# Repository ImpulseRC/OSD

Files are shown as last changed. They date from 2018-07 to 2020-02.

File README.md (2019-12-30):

<p align="center">
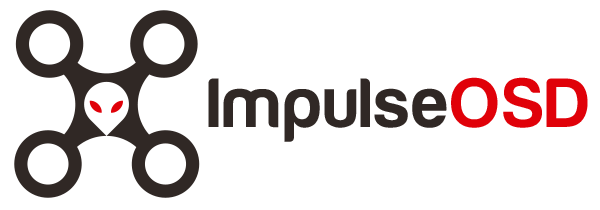
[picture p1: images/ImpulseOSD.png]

</p>

<p align="center">Official documentation resource for the ImpulseOSD hardware and firmware platform.</p>

## Contents

**[Home](https://github.com/ImpulseRC/OSD/wiki)** <br />
**[Getting Started](https://github.com/ImpulseRC/OSD/wiki/Getting-Started)** <br />
**[Betaflight+WolfPDB: Please read!!!](https://github.com/ImpulseRC/OSD/wiki/Betaflight-WolfPDB:-Please-read!!!)**  <br />
**[Rescue flash](https://github.com/ImpulseRC/OSD/wiki/Rescue-flash)** <br />

# Hardware <br />

* **[Wolf PDB](https://github.com/ImpulseRC/OSD/wiki/Hardware:-Reverb-Wolf-PDB)** <br />
* **[Apex OSD](https://github.com/ImpulseRC/OSD/wiki/Hardware:-Apex-OSD)** <br />

# Firmware <br />

* **[General Navigation](https://github.com/ImpulseRC/OSD/wiki/Firmware:-General-Settings)** <br />
* **[Basic Setup](https://github.com/ImpulseRC/OSD/wiki/Firmware:-Basic-setup)** <br />
* **[OSD labels/items](https://github.com/ImpulseRC/OSD/wiki/Firmware:-OSD-labels-and-items)** <br />
* **[Video Transmitter](https://github.com/ImpulseRC/OSD/wiki/Firmware:-Video-Transmitter)**
* **[Battery](https://github.com/ImpulseRC/OSD/wiki/Firmware:-Battery)**
* **[RSSI](https://github.com/ImpulseRC/OSD/wiki/Firmware:-RSSI)**
* **[Camera control](https://github.com/ImpulseRC/OSD/wiki/Firmware:-Camera-control)**
* **[GPS + Magnetometer](https://github.com/ImpulseRC/OSD/wiki/Firmware:-GPS)**
* **[LED strip](https://github.com/ImpulseRC/OSD/wiki/Firmware:-LED-strip)**
* **[Advanced display](https://github.com/ImpulseRC/OSD/wiki/Firmware:-Advanced-display)**
* **[Graphical OSD options](https://github.com/ImpulseRC/OSD/wiki/Firmware:-Graphical-OSD-options)**

# Config Tool GUI

* **[Install](https://github.com/ImpulseRC/OSD/wiki/Config-Tool:-Install)**
* **[Screen Designer](https://github.com/ImpulseRC/OSD/wiki/Config-Tool:-Screen-Designer)**
* **[Fonts](https://github.com/ImpulseRC/OSD/wiki/Config-Tool:-Fonts)**
* **[OSD Settings](https://github.com/ImpulseRC/OSD/wiki/Config-Tool:-OSD-Settings)**
* **[Flashing](https://github.com/ImpulseRC/OSD/wiki/Config-Tool:-Flashing)**
* **[Activation](https://github.com/ImpulseRC/OSD/wiki/Config-Tool:-Activation)**

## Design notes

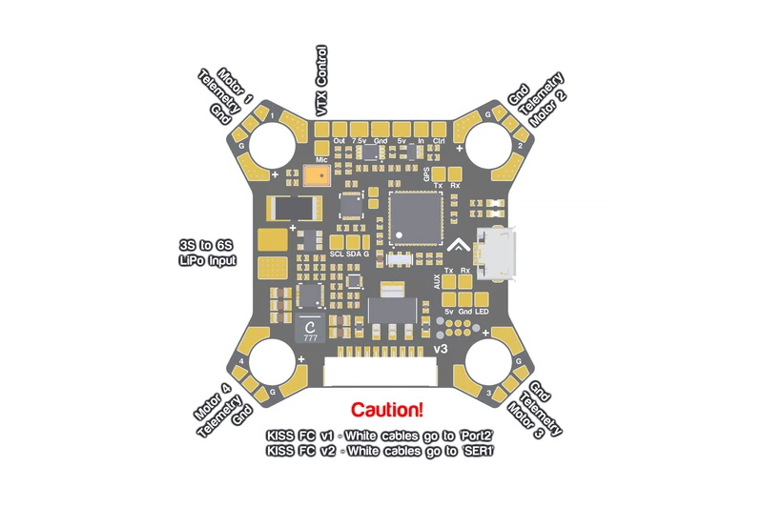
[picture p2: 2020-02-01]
images/Wolf/WolfV3_KISS_Pinout.jpg

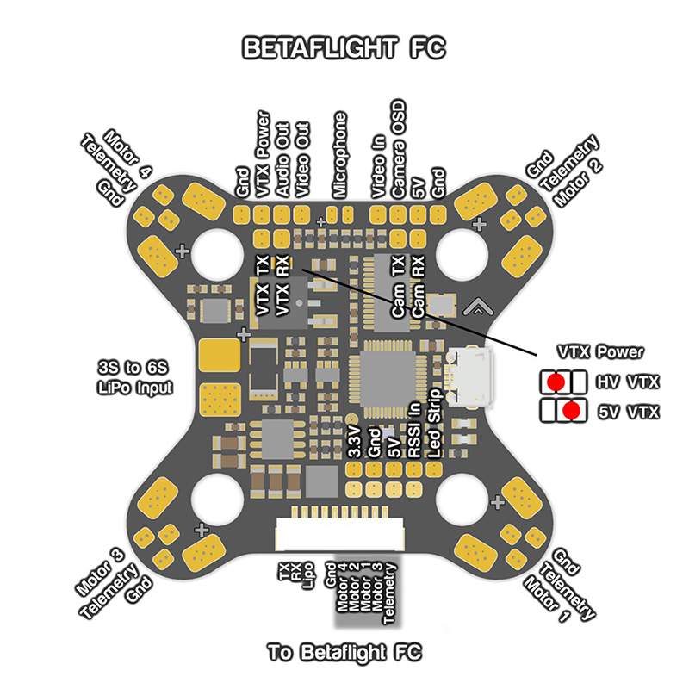
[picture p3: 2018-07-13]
images/Wolf/Wolf_BF_Pinout.jpg

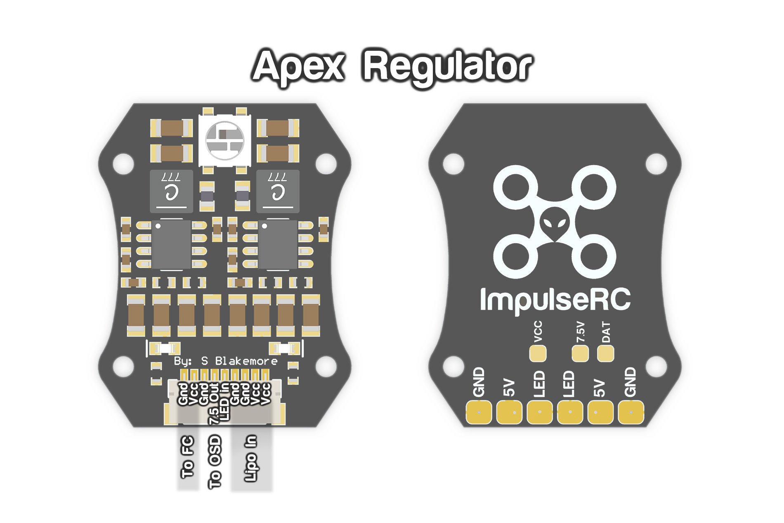
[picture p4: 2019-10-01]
images/Apex_OSD/Regulator_board_pinout.jpg

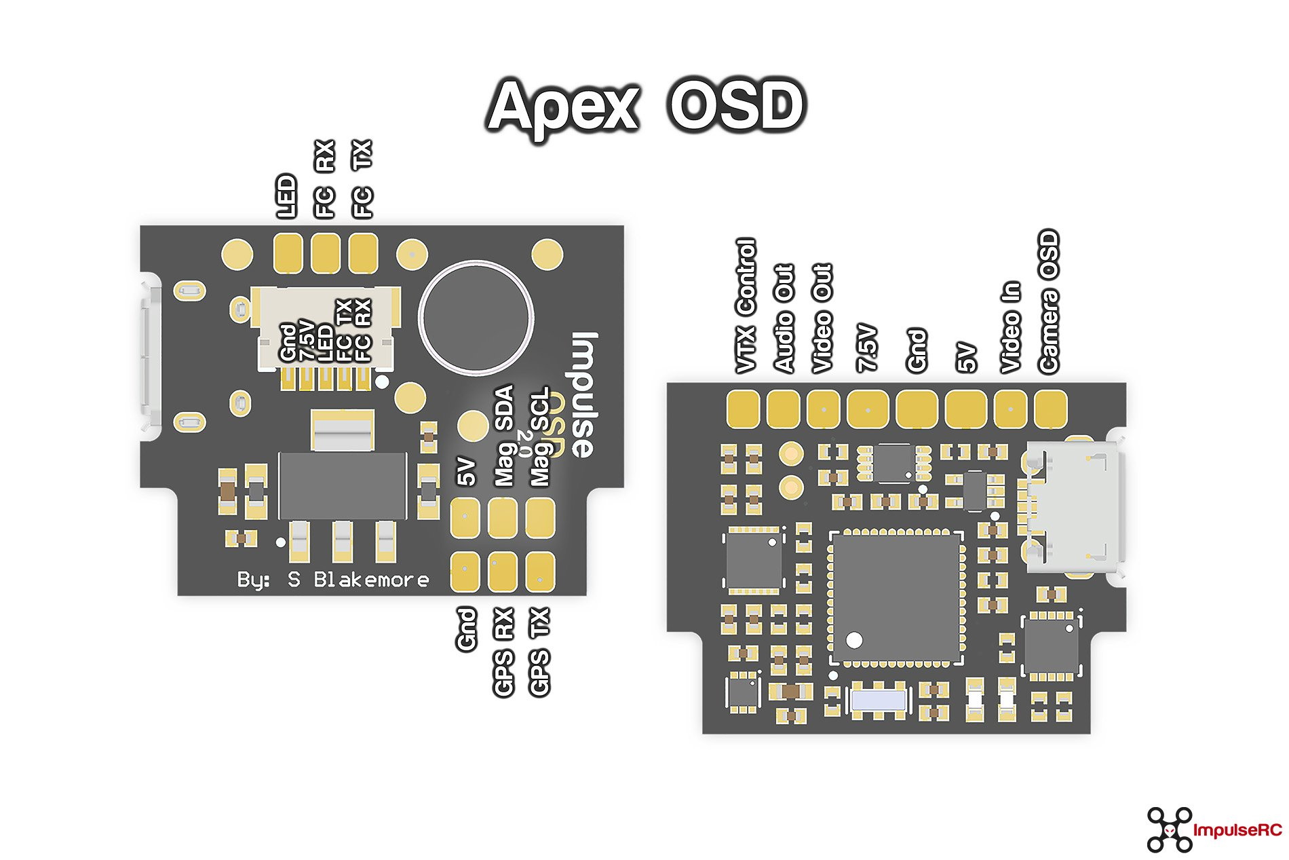
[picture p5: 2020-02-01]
images/Apex_OSD/Apex_OSD_pinout.jpg

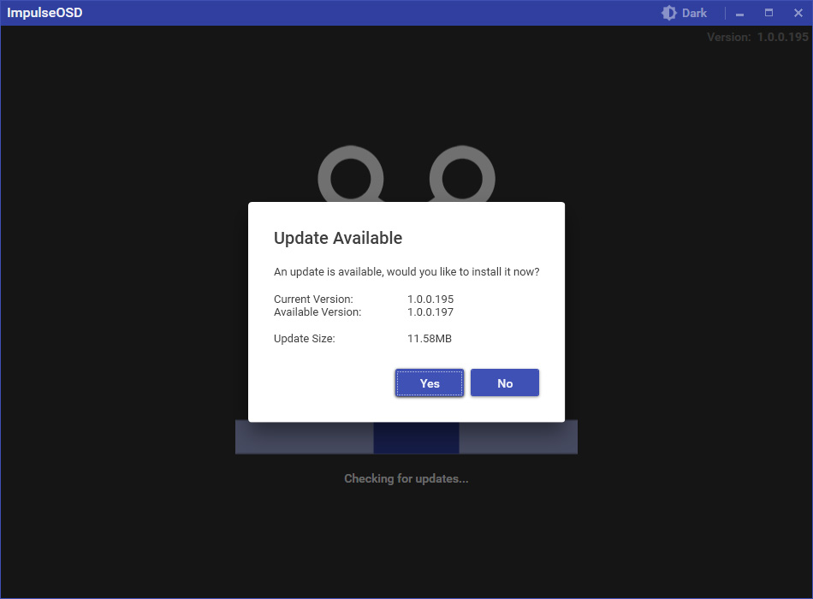
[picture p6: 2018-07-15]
images/ConfigTool/UpdateAvailable.jpg

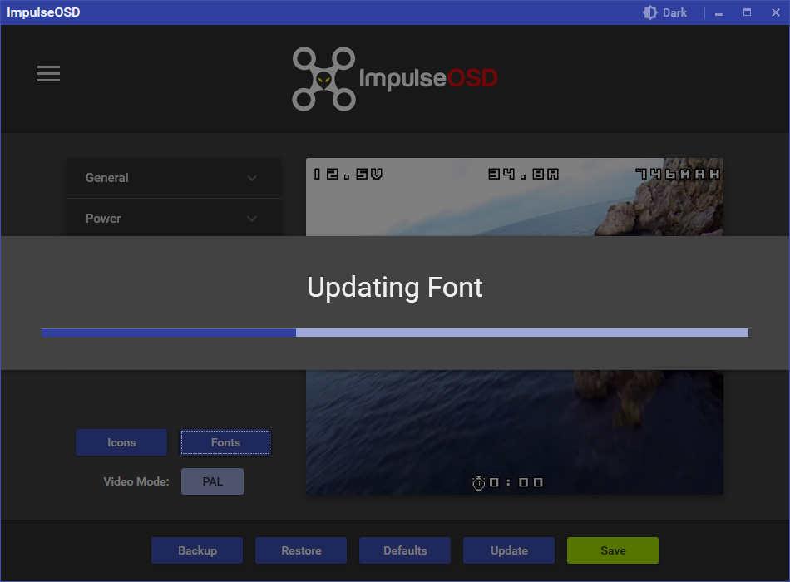
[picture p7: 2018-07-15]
images/ConfigTool/FontUpdating.jpg

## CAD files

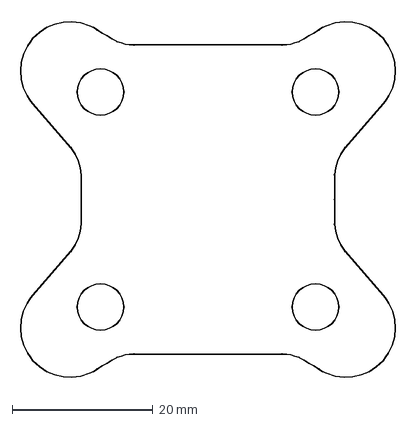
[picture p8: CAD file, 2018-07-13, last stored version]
images/Wolf/Wolf_Outline.dxf
54.3 x 52.0 mm

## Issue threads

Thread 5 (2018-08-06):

Unify pro - Smartaudio + microphone audio

FPVlog, 2018-08-06:
Hi

I read the manual and couldn’t find anywhere if it is possible to wire the Unify so it uses both smartaudio and audio from the microphone.

Is it possible at all? Should I jump the two pads and see if it works?

Cheers

awolf78, 2018-08-06:
Yes, jump the two pads. Solder the SmartAudio wire to the VTX TX pad on the WolfPDB. Then solder a small wire from VTX TX to the Audio pad.

In rare cases this can disrupt SmartAudio communication - then you might have to make a choice between Audio and SmartAudo. Not much we can do about it, that is a design issue of the Unify VTX. TBS recently came out with a Unify version with separate Audio and SmartAudio wire...

mortenb1337, 2019-01-03:
I had the same question, and came here. Did it work for you?

greezmen, 2019-03-28:
any plans for smart audio 2.1 support? or iam doing something wrong  its nit working with my hv pro race v2 unify thank you

awolf78, 2019-03-29:
SA V2.1 already implemented but not released yet, I can get you a beta if you like.

question2019, 2019-04-12:
hi, pls can u send me the link to the beta with SmartAudio 2.1 Support?
Thanks!

redoakleaves, 2019-04-12:
It is supported by the new firmware-version which is out since a couple of days, i guess. You should be able to update it right now.

question2019, 2019-04-12:
works perfect !!! thanks

TinoFpv, 2020-01-04:
Hi guys, noob here needs help.
I got a foxeer predator v4 on a tbs unify pro v3, the impulse ods have from left to right VTX control, audio out, so I have to bridge them?But when I do so i can't here the audio.
What to do?
Thanks and sorry for the noob question, first build.

awolf78, 2020-01-04:
I assume you are using the Apex OSD. Easiest is to strip the SmartAudio wire from the Unify a bit longer and solder it across both the VTX control and Audio pad. Please check that you have the volume turned up on your goggles. Are you sure the audio on your goggles is working?

TinoFpv, 2020-01-04:
Thanks awolf78, it was the jack not going right in.
I soldered now vtx and audio together on the apex osd.It works well.
Last question is what to do with the violet cable coming out from the foxeer.
Don’t now where to solder it :/
Many thanks for help.

awolf78, 2020-01-04:
The Violett (=Purple in Englisch) is the current sensor I guess. That one is not necessary. Make sure the VTX ground and camera ground are both soldered to the common ground pad.

TinoFpv, 2020-01-04:
Purple, exactly!All ground cables are fine.Apex osd is showing the right leds, so I think It is ok.
Thanks again awolf!

MrMPod, 2020-03-01:
> Apex OSD. Easiest is to strip the SmartAudio wire from the Unify a bit longer and solder it across both the VTX control and Audio pad.

but am I right that to change my vtx chanels I need PC computer and ImpulseRC OSD application ?
or is there way to change my vtx chanels and power without computer ?

awolf78, 2020-03-01:
No, you can change those in the field on the OSD menu. Read [here](https://github.com/ImpulseRC/OSD/wiki/Firmware:-Video-Transmitter)

MrMPod, 2020-03-01:
so is it necessary strip  the SmartAudio wire or just solder bridged the two pads VTX Control to the Audio Out pad on APEX OSD (I have already connected audio to my Unify VTX)

awolf78, 2020-03-01:
You can strip the wire longer or bridge the two pads - whatever is easier.

MrMPod, 2020-03-04:
you are right - strip the SmartAudio wire is easier than bridged the two pads :)
and it is working great, thank you very much for help

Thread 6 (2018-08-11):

Wrong ESC Speed/Temp with BLHeli_32?

milindur, 2018-08-11:
Hello,

today I installed the Wolf PDB in my Reverb together with the Bardwell F4 AIO FC (Betaflight v3.4.1). The ESCs are Airbot Wraith32 v2 with latest BLHeli_32 v32.52 firmware (beta). The ESC current seems to be okay, but temperature and RPM are way off.

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

This sounds similar to this issue: bitdump/BLHeli#318

awolf78, 2018-08-11:
Yes, this is a known issue. I have done lots of improvements for BF support lately and I'm overdue for a new release. Need to do some more testing which is challenging with all this rain we have here...

milindur, 2018-08-11:
Thanks! Good to know about the fix, so it is not an issue of my build. If I can help testing anything regarding BF, please let me know.

awolf78, 2018-08-12:
Fixed in V19.8

Closed 2018-08-12.

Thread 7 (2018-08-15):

Wrong KV and Min Voltage in Statistics

milindur, 2018-08-15:
Hello,

I am using the latest firmware for the OSD (19.8) with BF 3.5.0 and Wraith32 BLHeli_32 ESC (with firmware 32.52). In the statistics after a flight the calculated KV and also the min voltage (hopefully) seems to be sometimes wrong:

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

In this case only stats of ESC 3 and 4 are wrong, ESC 1 and 2 seem to be fine. After another flight all ESC stats were affected.

awolf78, 2018-08-15:
Please update to 19.8 by connecting the GUI

awolf78, 2018-08-15:
Is the autonomous telemetry option disabled on all your ESCs?

awolf78, 2018-08-16:
Ok, Wraith V2 ESCs? Not the mini ones, correct?
I have the same on my 6S quad and will beat a few more packs through it. Might have to get used to this since the KV is calculated by voltage and RPM. Somehow the voltage reported by the ESC must have gone as low as 0.3V for some reason which caused such crazy high KV numbers (or negative ones because it overflowed).

milindur, 2018-08-16:
Correct, Wraith32 V2 35A. Since I am still quite new to FPV and mini quads, I primarily did cruising with low to mid throttle and only sometimes pushed throttle to max for testing. I just checked my screenshots. In all cases where the KV was too high or overflowed, the min voltage of that ESC was 0.30V. So maybe this is more an issue of the BLHeli_32 firmware?

Closed 2019-12-30.

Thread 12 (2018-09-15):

No Audio just weird clicking Sounds

Richygoat, 2018-09-15:
Hello,
today i replaced the Steele PDB against the Wolf PDB an i don't have audio anymore.
vTX is the ImmersionRC Tramp.

When i disconnect the Audio wire from the PDB there is silence in the headphone. Connect it back only loads clicking sounds.

Newest firmware ist flashed.

Everything else is working fine.

regards

awolf78, 2018-09-15:
Did you solder the microphone on the WolfPDB? Can you show some pictures how you have soldered everything?

Richygoat, 2018-09-15:
Yes microphone is soldered on. And here are some pictures.

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

Richygoat, 2018-09-15:
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

awolf78, 2018-09-15:
Most probably a defective microphone. Please contact your dealer for a replacement. Sorry this happened to you.

Richygoat, 2018-09-15:
That was my thought too. But when i desolder the microphone this noise sound is still there.

Richygoat, 2018-09-15:
i could try to solder the microphone from my Steele PDB in the Wolf PDB when they're the same.

Richygoat, 2018-09-16:
I have tried the working microphone from the Steele PDB on the Wolf PDB. Still don’t working. After putting it back on the Steele PDB Everything working fine again.

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

awolf78, 2018-09-16:
Sorry this happened to you. Please contact your dealer for a replacement.

Richygoat, 2018-09-17:
Yes. I tried 2 TrampHV. Both are working fine on the Steele PDB.

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

awolf78, 2018-09-17:
OK, then you need to have your board replaced unfortunately.

Closed 2019-12-30.

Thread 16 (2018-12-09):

Some Display Options Not showing When Selected

awmondy, 2018-12-09:
I've searched this thread, impulserc github and googled and could not find an answer to my problem. A few options I selected to show on the display isn't on the screen. For instance, I had the vtx channel and vtx power on the screen. I removed the vtx channel and it was no longer displayed. I added the channel back and it did not show on the screen. Other display options are not showing either. I used the Impulserc app to default the pdb and had the same issue. Has anyone else had this issue?

Impulserc/Wolf fw 22.9
Kiss v1 fw 1.3-rc36c

awolf78, 2018-12-09:
Did you click Save in the ImpulseOSD GUI after you added the VTX channel back?

awmondy, 2018-12-10:
I did click save in the GUI.

FYI - RSSI, timer and GPS data doesn't show at all. I can add and remove
callsign.

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

awmondy, 2018-12-11:
I found what was causing the issue. I added a GPS (BN180). I connected tx to tx and rx to rx, when I should've had tx to rx and rx to tx. I reversed the connections at the pdb and the missing options were displayed on the screen. I find it odd that having the GPS connections reversed could cause some options not to be displayed.

awolf78, 2018-12-11:
It doesn't make sense for the OSD to display labels when there is no data available for them. Some pilots just plug in a GPS occasionally and then they will only see the GPS related labels when it is connected.

Closed 2019-12-30.

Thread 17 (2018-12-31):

Micro Swift 3 Serial Communication Wolf PDB and Kiss v2

Ayougo, 2018-12-31:
Wolf PDB with latest firmeware
Kiss v2 with RC36I firmware
Micro Swift 3 connect via TX/RX  (TX from Swift to RX on Wolf PDB, RX from Swift to TX on Wolf PDB)

Issue: No Internal OSD menu on new swift 3 micro with serial camera control

Yaw left, toward bottom or zero throttle, hold for several seconds, enter menu, select "camera control", Yaw Left  == No Internal OSD menu

mkct93, 2018-12-31:
Same here friend. 😐

awolf78, 2018-12-31:
Go to SETUP->CAMERA CONTROL and change CAMERA CONTROL to SERIAL.

awolf78, 2018-12-31:
Cam RX connected to PDB Camera TX?

mkct93, 2018-12-31:
Yes. I swapped it around both ways in case the camera wasn’t labeled correctly. Still nothing. I’ll try another camera tonight that I know works with the serial connection and post the results. Also I am using the rev1 pdb.

mkct93, 2018-12-31:
Fantastic! I’ll give it a go tonight. Pdb is awesome by the way. Great piece of kit. 👍🏻

mkct93, 2019-01-01:
That was it. Thank you so much.

Closed 2018-12-31.

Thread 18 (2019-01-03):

OSD stopped working

Anckero, 2019-01-03:
My OSD is not showing up anymore with my WolfPDB. I don't get values nor ImpulseRC boot logo.
The green LED is on but the red one is not flashing as it should.
The PDB is not connecting to my PC.

I searched online and found on RCgroups a guy who stopped a firmware update by mistake and he had the exact same issues. So even if my problem is not coming form a bad firmware update I followed the steps.
I temporarily bridged SDA and GND then connected the USB. This trick worked, the red light was flashing and the PDB was recognized by my PC. As an update was available I flashed it and it went well.

But then I unplugged the XT60 and USB and this issue is still there on my next attempt to connect the XT60, no red LED flashing.

I'm using a KISS FC v1.03 FW1.3-RC36i

awolf78, 2019-01-04:
Do the SDA and GND trick again, but this time select Full Chip Erase in the GUI before you flash.

Anckero, 2019-01-04:
Fantastic! All is back to normal.
Thank you very much awolf78! 😃

Oberlurch3000, 2019-05-01:
Please could you tell me how this trick works? I've the same problem since today. Just no OSD in the FPV screen and the red LED is off. WIndows tells me that the device has not been recognized. Why is this happening? I did no changes to it in the last few weeks.

Anckero, 2019-05-01:
Hi @Oberlurch3000
Here is the RCGroups thread I first found the instructions: https://www.rcgroups.com/forums/showthread.php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

Just follow the instructions as per Awolf78's comment on RCGroups and you should be fine. If the problem persists you may have to do the "Full Chip Erase" thing in the GUI as Awolf78 told me to do on this GitHub thread. :)

Oberlurch3000, 2019-05-01:
Wow thanks! I like things that work ;). But very strange that it happend anyway.

Anckero, 2019-05-01:
Yeah it's pretty strange. Mine stopped working like yours, without any reason. But it has been working great since this fix so you should be fine too. :)

Brightontillifly, 2021-07-10:
> Do the SDA and GND trick again, but this time select Full Chip Erase in the GUI before you flash.

this totally worked for me nice one Wolf!

Ub6ib9, 2021-08-28:
Awesome so there is hope. Out of nowhere the osd quit working and gps wasn't getting a lock. I'm hoping this process will work. I'll chime back in after trying.

Closed 2019-01-04.

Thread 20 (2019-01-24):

"Battery Charged ?" show on deplay

climbhi2, 2019-01-24:
Hello,
I would like to thank you for everything you’ve done to make this OSD the best.

I'm running the latest frame ware and have been seeing "Battery Charged ?" come up blanking when I plug in a battery. When I arm the message goes off. Is this new? I have tried to isolate it by changing batteries on my goggles and transmitter. Is this just a message “battery charged?” to remind you to check the battery before you fly or have I changed a setting that I’m not aware of.
Thank You
Tommy

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

awolf78, 2019-01-26:
This is voltage based and appears when you plug in a battery that does not appear to be at charged voltage.

whig0, 2019-07-20:
This warning is shown even with 4.15 Volts. Is it possible to disable it? Or can it be adjusted somehow?
Thanks.

awolf78, 2019-07-29:
I have made it less sensitive and dropped the warning voltage to less than 4.10V per cell. Will be included in next release.

whig0, 2020-09-12:
Unfortunately I still have the problem. The warning shows for me as soon as the voltage drops under 4.1V Per Cell.
Is there still no possibility to just disable it?

awolf78, 2020-09-12:
The warning disappears as soon as your arm. It is just a reminder that your battery may not be fully charged - which is the case at 4.1V.
Alternatively you can add a voltage offset and raise the voltage by e.g. 0.1V in the [Battery menu](https://github.com/ImpulseRC/OSD/wiki/Firmware:-Battery#battery-menu)

whig0, 2020-09-12:
Yes I did that already. But the warning appears as well just with .1V offset at 4.0V :-)
It even shows when not armed.

awolf78, 2020-09-12:
But it disappears when you arm? It is just a reminder that your battery is not fully charged...

whig0, 2020-09-15:
Sorry for late reply.
No it does not disappear. And it's in the middle of the screen.
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

awolf78, 2020-09-15:
Hm, that is very odd. Can you please describe your setup and how you have it wired up? Do you see a message ARMED or DISARMED when your arm/disarm? What version ImpulseOSD is on there?

whig0, 2020-09-16:
It's wired like in the Philipp Seidel Wiringplan.

Impulse OSD Version is V86.25
Kiss FC v2 (1.3RC45y)
4x Kiss ESC 32A
TBS UNIFY Pro32 VTX @7.5V
Foxeer Falkor Cam @5V
No Mic, No GPS, No LEDs
Spektrum Receiver
4S LiPos

Yes, I get the Armed and Disarmed messages.

awolf78, 2020-09-16:
Can you try flashing again?
If that doesn't help I would need a backup of your ImpulseOSD and KISS FC configuration...

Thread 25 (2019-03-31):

No Connection to FC

dawiddi, 2019-03-31:
Hello there,
I just build my first wolf pdb setup with a brand new board and a Kiss FC V1. After updating all firmwares (Kiss on 1.3RC36 Stable and the latest OSD firmware) and do all settings (Dummy VTX, No Logger/OSD) I have the following issue.
After booting up every time the message "Detecting FC Type" shows up. Sometimes after a while, the message just disappears, other times it follows "No connection to FC" and the OSD hides. I already checked the port cable, it seems to be everything ok. I resoldered the cables to the VTX and the cam aswell. The Kiss and the PDB are brand new.

I've read all the issues related to my problem, but could not find a solution. Can you help me?

Thanks a lot.

Hydromaster1, 2019-04-03:
I am having the same issue. Kiss FC V2, tramp vtx, & crossfire. The problem goes away when GPS is disconnected. Using an RDQ  M8N GPS. GPS data appears and disappears.
Thanks for all the hard work and awesome firmware!!!

awolf78, 2019-04-04:
I just released a fix for this issue, please connect GUI and update

Hydromaster1, 2019-04-05:
Update complete and the issue is gone. Only thing I noticed was the home arrow spins continuously.
Could this be due to close proximity to the home point. I only did one test flight about 300 meters out.
Hope to get another flight in tomorrow. Many Thanks!!

awolf78, 2019-04-05:
If the home arrow keeps spinning then the GPS has not been able to establish a fix yet. You can turn the satellites label on which will show you how many satellites the GPS has found. For a first fix it can take several minutes...

Hydromaster1, 2019-04-05:
Got it.
Many thanks!!

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

dawiddi, 2019-04-05:
Many thanks. I couldn‘t try flying yet, but the message disappeared in standby.

dawiddi, 2019-04-07:
So I got the time to test it today. But unfortunately the voltage, power and mah values were way too high (330 V, 150 A etc.) and after a short while it lost the connection to the FC. What should I do?

awolf78, 2019-04-07:
Can you revert to V24.11 and see if you still have the same issue?

dawiddi, 2019-04-13:
Hello,
I just got the chance to test it today. The wrong voltage values are gone, but instead the "Detecting FC Type" and "No connection to FC" comes back after a few seconds of flight.
Any further suggestions?

awolf78, 2019-04-13:
If you reverted to V24.11 and you get a "Detecting FC Type" then there is definitely something wrong with your board or wiring. Do any of the chips or regulators get very hot shortly after you plug in? Can you post some pictures of your wiring?

dawiddi, 2019-04-14:
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

I already measured the wiring to the Kiss FC, all cables are okay. When I touch the PDB after powering, it stays cool. It seems good. But my Kiss FC gets very hot near the USB port. I thought, that would be normal because it is a new one.

I attached some pictures of my wiring.
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

awolf78, 2019-04-14:
Wiring seems OK. What type battery are you running? 4S, 5S, 6S?
VTX is connected to HV power - not sure which VTX you are using.
Did you change anything in your serial configuration of your KISS FC. Check in the KISS GUI Advanced tab. Please post a screenshot of that.

dawiddi, 2019-04-14:
Battery is 4S, I use a Unify Pro HV, that works great.
I attached a screenshot of the advanced tab.
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

awolf78, 2019-04-14:
Strange that your Yaw Filter is at 92 - should be at 35 or 40. But that should not matter for the FC communication. Do you have another FC you can try?

antantantantant, 2019-05-03:
Hi!
I have this same 'detecting fc type' - 'no connection to fc' problem with wolf pdb + matek f405-std combo. PDB seems to work fine, it has updated itself to v40 something, fc is working and is configurable in betaflight app, it's connected to a crsf receiver and reacts to controls, I can arm (and probably fly) the quad, but can't control the PDB with stick commands or get BF OSD items to show on screen etc.
I've attached some images of my wiring (sorry for the mess :) ). I'll make more photos if you need to see details, just point me where you need to look.
Any suggestions appreciated :)
Thanks!

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

awolf78, 2019-05-04:
Did you read [https://github.com/ImpulseRC/OSD/wiki/Betaflight-WolfPDB:-Please-read!!!](url)?
Configured MSP for the UART you are using for FC communication to the PDB?

antantantantant, 2019-05-04:
Believe it or not, I missed the article, although I searched for instructions :/ Sorry!
Anyway, just set up BF as instructed and everything works now :)
Thanks!

AiroFpv, 2019-05-11:
So i have also been having this same issue, new board, connect to gui and flash newest fw. When i first plug in, osd is fine and i can access menus for a bit then "no connection to fc" shows up. Same if i go for a fly, after a few seconds, osd goes away and no connection to fc. Any tips?

AiroFpv, 2019-05-11:
Link on your last reply doesnt work either. Cant read the please read!

awolf78, 2019-05-11:
[Please read](https://github.com/ImpulseRC/OSD/wiki/Betaflight-WolfPDB:-Please-read!!!)

awolf78, 2019-05-11:
Can you describe the setup you are running? FC type, lipo voltage, etc.

AiroFpv, 2019-05-11:
Sorry, i deleted the link comment cause i am running kiss v1 fc and 32a escs, 5v unify, 4s with caps on esc's in preparation for 6s transition.

awolf78, 2019-05-11:
What FW are you running on the KISS FC?
Not sure if you have tried to run 6S on your rig, but the KISS V1 cannot handle 6S lipo voltage. Most of the time the voltage regulator gets damaged if you try to run 6S and although it still flies you get these connection issue. Not 100% sure that is the issue, just one possibility.

StevenFpv, 2019-09-24:
ciao ragazzi, ho lo stesso problema appena collego la lipo mi rimane il logo impulse con la scritta DETECTING FC TYPE.  una build che funzionava, ho sostituito con una nuova kissv2 e nuova ricevente r9 slim plus, ho aggiornato con l 'ultimo fw di impulse e l ultimo su gui, aggiungendo il GPS. ho staccato il gps e provato fw precedenti ma non sono riuscito a risolvere il problema.

vladsubbotin44, 2019-10-29:
pdb wolf writes in OSD Detecting FC Type. flight controller mamba f405 mk2. whats problem ?

sblakemore, 2019-10-30:
@vladsubbotin44 please ensure that you have updated to the latest version of ImpulseOSD. Can you also check that you have MSP enabled for the correct serial port in BF and that you have soldered RX to TX and TX to RX.

AiroFpv, 2019-11-09:
So, something really weird just happened, went to update the osd, run
impulseosd plug in, says do you want to update, click yes then error
message saying lost connection try power cycling and re run gui. Now when i
plug in the computer it says that device isnt working correctly, impulseosd
gui just sits there and doesn't see it and impulserc driver fixer doesnt
see it either. No flashing heartbeat, should i try to solder sda and gnd or
did it fry?

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

awolf78, 2019-11-09:
[https://github.com/ImpulseRC/OSD/wiki/Rescue-flash](url)

blackdrone911, 2020-01-12:
> If you reverted to V24.11 and you get a "Detecting FC Type" then there is definitely something wrong with your board or wiring. Do any of the chips or regulators get very hot shortly after you plug in? Can you post some pictures of your wiring?
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
shneakypete, 2020-07-05:
Had this issue… for me the harness on the pdb had come loose from the solder joints and was getting intermittent connection. Ended up replacing the pdb cause when I tried to resolder the traces came off

darkjedi15486, 2020-07-05:
I'm not using a pdb. Im using the kiss 4 in 1 and the kiss v2  with apex irc osd and regulator board

awolf78, 2020-07-05:
First I would re-seat the connectors and make sure the pins inside the connectors are not bent in a weird way. I would still route the cables above the FC to eliminate any possible EMI issues (not every ESC is the same even if it is the same brand). If all of that doesn't help you can try a new Apex OSD harness.

darkjedi15486, 2020-07-05:
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

Well thats how I have mine wired up. I moved the wires away from the motor solder joints and reflashed the osd board and had a 4 min flight with no issue so hopefully its a problem thats gone for good.

LocNgu, 2020-07-10:
I am having the same "no connection to Fc" Problem.
I am running Fettec Fc, Fettec 4in1, Apex Regulator, Apex Osd Board, all wired up using the Kiss Harness, 6s, low esr cap, and fettec spike absorber. I tried running the wire over the fc and powering the Fc from the regulator board instead of the esc. Reflashed everything to most recent updates as of today.
I can reproduce the issue pretty consistently. Every time the amp draw goes over aprox 5A the issue occurs and go away when amps falls back.

awolf78, 2020-07-10:
1. Remove the GND wire from the ApexOSD harness between Apex Regulator and Fettec FC
2. Remove the extra Lipo wire between Fettec ESC and FC
3. Add a GND wire between ApexOSD (can use e.g. GPS GND) and Fettec FC (use any GND that is convenient)

LocNgu, 2020-07-13:
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

Did all the steps above and they do help. Issue doesn't appear that often, but still does from time to time. Still not quite what one would expect from a pretty expensive osd board.

awolf78, 2020-07-13:
There are also some firmware fixes, not only on our side, also on KISS. What KISS FW are you using?

darkjedi15486, 2020-07-13:
I'm using rc40i on my v2.

awolf78, 2020-07-13:
Consider upgrading to 40o. Alexander Fedorov has also made some changes (we worked closely together on the communication issues). You can find his latest FW on Patreon.

darkjedi15486, 2020-07-13:
Is 40o available on the kiss gui

awolf78, 2020-07-13:
Yes

LocNgu, 2020-07-14:
>
>
> There are also some firmware fixes, not only on our side, also on KISS. What KISS FW are you using?

FETTEC_KISSFC-1.3-RC40o

ebeez, 2020-09-12:
Hi,
Can anyone post a picture of how they have used the Apex regualtor/OSD wiring harness to the FC? I am still getting the "connection lost to FC" on my build: Fettec 45 ESC, Fettec FC (both flashed to most current version), apex regulator board/OSD

awolf78, 2020-09-12:
1. Route OSD wires above FC, not between FC and ESC (or below ESC)
2. Remove GND wire between FC and Apex Regulator
3. Remove Lipo+ between FC and ESC
4. Add GND wire between FC and ApexOSD (any GND pad on either side will do).

ebeez, 2020-09-12:
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

Thank you for the quick response! Will give it a shot.

ebeez, 2020-09-14:
Thank you!!! Worked like a charm!

blackdrone911, 2020-11-14:
Hello again,
now I have two v3 PDBs where the red LED is constantly on.
The trick with SDA and Ground doesn’t work.
Some questions:
1. Why this happened the second time?
2. How could it be solved, detected the broken part?
3. Is the problem known from the manufacture?

I am really tiered with this PDB after spending so much time to find the problem :(

awolf78, 2020-11-14:
Did you select "Full chip erase" when you forced the bootloader by bridging SDA and GND?

blackdrone911, 2020-11-14:
I can’t select anything. The software doesn’t detect the PDB. I tried with windows and also with MacOS.
Than I removed all solderings (cam, ESCs, FC and so on) and tried again. Same result.

awolf78, 2020-11-14:
When you bridge SDA and GND and plug a Lipo in - does the red LED start blinking then?

blackdrone911, 2020-11-15:
No

awolf78, 2020-11-15:
OK, I suggest you open a support ticket with the dealer you bought the PDBs from - it is up to them to decide how to handle this.

tommymcnab, 2021-07-21:
Having an issue with my gen one mr Steele Alien setup had it saying no connection to fc and then I hooked it up last night al of the sudden started working was micking around with it and the video started becoming grainy when I shook the unit and then it just dropped out back to no connection to fc I updated the fc and have also taken it apart and found two of the esc had loose wires still no fix though have resoldered connections to cam video transmitter am quite baffled with what to do so anything will help thank you in advance!!!!!!!

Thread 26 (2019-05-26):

Foxeer Predator V3 mini OSD + Futaba RSSI

DrHasch, 2019-05-26:
Hello there,

I connected my **Foxeer Predator V3** to the PDB but i am not getting into the menues. Hooked the  OSD pad to the OSD pin of the cam and the ground pin to the pad of the supply. I tried alot of settings but none of them worked.

As i wanted to use my old **Futaba T7C** i got myself a **ElgaeRX E6208 8CH Mini** receiver from Bangood, which is working fine and does his job. As it has a **RSSI** pad i wanted to ask whether I can connect it directly to the RSSI in pad of the PDB?

Thanks alot,
Thomas

awolf78, 2019-05-26:
https://github.com/ImpulseRC/OSD/wiki/Firmware:-Camera-control#troubleshooting

https://github.com/ImpulseRC/OSD/wiki/Firmware:-RSSI

DrHasch, 2019-05-26:
Already looked up this pages but it did not work

awolf78, 2019-05-26:
Did you wire up the OSD wire of the Predator camera? How did you wire it up? Can you post a picture?

RSSI: Yes, try connecting it to the RSSI pad on the WolfPDB. Then you have to see what readings you get and adjust min and max accordingly.

DrHasch, 2019-05-26:
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
Gnd of the camera (black cable) to the gnd pad on the supply of the camera on the PDB. White cable to the OSD pin on the board.

For the RSSI, where can i look up the readings?

awolf78, 2019-05-26:
Try removing the gnd wire coming from the OSD plug on the camera. That is not necessary anyhow since you already have the camera gnd connected.

RSSI: I don't know what RSSI values your receiver will output - that could be different even if you have two of the same. You will have to look at the values in the SETUP->RSSI screen in the OSD while keeping your radio close (about 1m or 3ft distance) or move it far away (or turn it off).

DrHasch, 2019-05-27:
So i managed to get into the camera control. Somehow it dit not work when i had the setting on predator.

The RSSI pin provides a voltage of 3V when connected and 0V when the remote is switched off. But the RSSI IN pin on the PDB does not really read it.

awolf78, 2019-05-27:
Did you set the RSSI channel to "ANALOG" in SETUP->RSSI? On the bottom of the screen you can see the values.

DrHasch, 2019-05-27:
Yes i did. The value just jumps from 0 to maximum 3 not more... But on 3V it should be like 2000? Am i right?

awolf78, 2019-05-27:
Connect GUI and update to V44.12.
Looks like I picked the wrong ADC channel for the RSSI input - sorry about that.

DrHasch, 2019-05-27:
No problem ;) thanks for the help

Closed 2019-05-27.

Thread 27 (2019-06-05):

GPS not detected

Anckero, 2019-06-05:
Hi,

I'm having a hard time making my BN-180 module work with my Wolf PDB.
Here is my setup:
- KISS FC v1.03 FW1.3-RC36i (latest update available)
- Wolf PDB  Rev1 FW45.12 (latest update available)
- GPS BN-180

The GPS is wired correctly to the Wolf PDB, it flashes in blue and after a bit of time it flashes in red too (meaning it got a GPS fix).
Just in case, here is my wiring:
BN-180 red wire (3.0V-5.5V) → "5V" pad of the PDB (on top of the "GPS TX" pad)
BN-180 green wire (RX input) → "GPS TX" pad of the PDB
BN-180 white wire (TX output) → "GPS RX" pad of the PDB
BN-180 black wire (GND) → "Gnd" pad of the PDB (On top of the "Mag SCL" pad)

I turned on all the GPS items in the OSD but there is no data shown when I leave the OSD settings.

Could you tell me what I missed?
I noticed my FC is getting really hot when I plug the LiPo. The mAh count is going crazy fast!
I tried to unplug the GPS, same issue. Then I removed the 4 GPS wires from the PDB and no more overheating!
That's really strange because I checked and there is no shortcut between the GPS wire (without the GPS module connected to them).

A friend with a Kiss FC v2 and Wold PDB is facing the exact same issue with a BN-220 which is exactly the same hardware as my BN-180. No data and overheating.
I saw, here on GitHub, that you (the ImpulseRC devs) used a BN-180 in the development process so I really don't get why mine is not recognized.

Thanks in advance

awolf78, 2019-06-07:
Can you post some pictures of your setup please? I also need to know what else is connected to the PDB and how.

Anckero, 2019-06-10:
Hi awolf78,

I brought my setup to my work place and a colleague from the electronic team checked everything. We tried to wire up everything again and it worked.
The only difference was that I twisted the wires in the first place and my colleague told me that the power wires could create problem on the RX and TX wires. Now with strait cables the Wolf PDB and the GPS are talking to each other.
I will close this issue then, sorry for the inconvenience. :)
I didn't know that twisted wires could have this kind of effect.

Thanks for your support!

Closed 2019-06-10.

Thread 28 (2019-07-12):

Steele PDB only sometimes audio

Dragon-FPV, 2019-07-12:
Hello,

unfortunately I have no sound any more (it worked fine). I don't know when it started and how (perhaps crash), but now I only have sound for some time when I hit something (e.g. a branch) during the flight without crashing. But just for a while, than the sound is gone again.
It seems like a loose connection, but where?

I tried everthing, all wires are ok and correct soldered, I replaced them ... but at the end the same issue. I also didn't find out what I can do by myself to simulate what happens due hitting something.

I guess microphone is working as there is sound again and again. And it's fixed on the PDB.

What else can I try / could be the reason?

thx and greetz

(KISS FC V2, KISS ESC 32A, Steele PDB, TBS Unify Pro V3, 6S)

rauar, 2019-12-24:
I think this is the wrong repository. Steele PDB should be here: https://github.com/awolf78/KISS_OSD

Closed 2019-12-30.

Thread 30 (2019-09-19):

Cant connect to my wolf pdb with ImpulseOSD app in windows

charalambos12, 2019-09-19:
After updating to the last version of impulseosd app in windows i cant connect to my wolf anymore and i have the message in the attachment. What can i do?
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

awolf78, 2019-09-20:
Disconnect everything, reboot your PC, try again.

charalambos12, 2019-09-20:
Did it many times. Problem did not solved. Before updating the app everything was working perfectly.

awolf78, 2019-09-20:
Bridge SDA and GND pads temporarily. Plug in Lipo. Remove SDA and GND bridge. Connect USB and GUI and flash again, but this time click on "Full chip erase" before you flash.

charalambos12, 2019-09-20:
Thank you for your support!

charalambos12, 2020-01-27:
hello, after doing the procedure, at the end when i open impulseOSD program, i have a new message saying unexpected error, power cycle the device and I cannot continue with the re flashing. I have the same problem with two wolf pdbs v1 (they are working perfectly, except the connection with gui). Thank you in advance.

awolf78, 2020-01-27:
Do you have a different Windows PC or Laptop you can try?

charalambos12, 2020-01-27:
I tryied with mac laptop and I successfully updated the pdb to the latest version.

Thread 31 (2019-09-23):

Wolf PDB won't connect to Impulse OSD app

briankalski, 2019-09-23:
I can't get the Impulse OSD app to see my Wolf PDB.  I did flash the Steele PDB firmware to the board which I am assuming is the wrong firmware.  Is there somewhere I can get the Wolf PDB firmware?

awolf78, 2019-09-23:
How did you flash the SteelePDB firmware on the WolfPDB?

briankalski, 2019-09-23:
Using Xloader.  It was my first quad.

awolf78, 2019-09-23:
XLoader cannot flash the WolfPDB. Does the WolfPDB work (red LED is blinking and shows OSD)?

briankalski, 2019-09-23:
Everything works fine.  The OSD works.  I just can't connect to ImpulseOSD to change my OSD settings.  I ran the driver fixer and that won't connect either.  I tried a Mobula7 and it worked with that.

briankalski, 2019-09-23:
The last time I changed the OSD settings I had to unplug port 2 and flash the Steele PDB config tool.

awolf78, 2019-09-23:
The ImpulseOSD GUI does not work with the SteelePDB. You will have to flash the config tool if you want to make changes to your OSD.

Closed 2019-09-23.

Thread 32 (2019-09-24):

WOLF REVERB PDB OSD Not Recognizing KISS FC v2, multiple quads on powerup.

Struggen, 2019-09-24:
I have 2 Reverb's, both running KISS FC v2 & Wolf PDB rev 2 on latest firmwares that are experiencing failures to recognize the FC when the battery is connected. Reconnecting the battery temporarily resolves the issue. It is occurring every almost every other battery. The problem started occurring after I updated the PDB and KISS GUI's and then updated the firmware for both.

ReverbAlpha
Reverb 5"
Wolf PDB/OSD Rev 2
KISS FC v2
KISS 25amp ESC's
Frsky X4R-SB
ImmersionRC Tramp HV
RunCam Eagle 2
BN-220 GPS

ReverbBeta
Reverb 5"
Wolf PDB/OSD Rev 2
KISS FC v2
KISS 32amp ESC's
25v caps on ESC's
Frsky X4R-SB
ImmersionRC Tramp HV
Foxeer Predator Mini 3
BN-220 GPS
LED's on the FC powered by 5v Diatone regulator

awolf78, 2019-09-25:
Can you please update to V55.15 I just pushed?

Struggen, 2019-09-25:
I have updated one quad to 55.15 and have not had the issue occur during bench testing.

Closed 2019-10-24.

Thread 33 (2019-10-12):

OSD will not centered

carloscampos775, 2019-10-12:
Can't get APEX OSD to center vertically using 57.15. Can't move items to the top of the screen. Using RunCam Swift Mini 2 with TBS Unify Pro 5v

sblakemore, 2019-10-13:
What display device are you using, goggles or screen of some kind? Different displays often show different portions of the image.

Can you please get some DVR footage so we can see how things look?

Might also be worth doing a flash with full chip erase enabled to make sure the config is clean.

carloscampos775, 2019-10-13:
I'm using Fatshark HDO’s with RapidFire. I'm not having this problem with the Wolf Reverb PDB only the Apex OSD. It's also cutting off the back/exit item in the OSD menus. I will try the full chip erase and update the issue.

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

carloscampos775, 2019-10-13:
This is after a full chip erase. Still not working correctly. I have also tried another camera but the problem still persists.

Default OSD layout after full chip erase:
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

This is what I need to do in the configurator to get the OSD items to show on screen:
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

Herbiefpv, 2019-10-14:
I am also having this exact issue. I can adjust the osd side to side but it will not let me move it up. I can see something barley at the bottom. I also tried re flashing but no luck.

Herbiefpv, 2019-10-14:
Awesome thanks Sean!

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

sblakemore, 2019-10-15:
Thanks again for the feedback, I believe I just fixed this. We should have a new release soon for you to try!

sblakemore, 2019-10-15:
If you would like to test a Beta release with the fix I can enable your OSD for Beta updates. All you need to do is connect the OSD to the GUI and then press Ctrl+Shift+D and you will get a popup with your hardware ID. Then just hit Ctrl+C to copy the ID and paste it in here and I'll set it up for you!

carloscampos775, 2019-10-15:
I would like to try the beta. Here is my hardware ID

Device ID: 0011 1025 4847 750A 2037 7341

awolf78, 2019-10-15:
Please download the beta GUI from here:
[http://osd-storage.impulserc.com/deploy-beta/setup.exe](url)

That should offer you V59.15. Let us know how it goes.

carloscampos775, 2019-10-15:
Looks much better. If you could get it to center just a little high that would be perfect.

Default look after flashing
###
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

Herbiefpv, 2019-10-15:
O was i suppose to use a certain gui? I just used the latest one i got the
other day but it will centered mine lol

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

carloscampos775, 2019-10-15:
I was able to center the OSD by using the Advanced options. However, I have gotten a flickering OSD twice now since updating

Video of issue:
https://www.dropbox.com/s/xo40cu8j2zytp4t/PICT0051.AVI?dl=0

sblakemore, 2019-10-16:
@Herbiefpv Beta GUI not a requirement for this update, you will be fine :)

@carloscampos775 Vertical jumping like that is to do with the sync level your camera is putting out. You should be able to fix it by adjusting the sync detection level using the camera settings dialog in the GUI. There is a slider in there you can move up or down, will take some trial and error to find a value that works for you. Looks like it's about on the edge so probably will only take a small movement up or down to be stable.

carloscampos775, 2019-10-16:
@sblakemore I found the camera sync setting. I think i'm good. Thanks for your help ;)

Closed 2019-12-30.

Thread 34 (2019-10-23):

Apex OSD camera control w/ Foxeer Predator v4

bosbefok, 2019-10-23:
This camera has Day, Night, LED, BW mode presets which you can change by long pressing the right button on the remote control board.  I'm having an issue where camera control automatically changes to the next preset when you enter the camera control menu.

All camera control settings are stock with reference voltage of 2.33v.

Any suggestions?

awolf78, 2019-10-23:
What happens if you are not in the camera control menu? It does not change the Day, Night, LED, BW preset then?
The default reference voltage is 3.3V, not 2.33V

bosbefok, 2019-10-23:
It only changes mode when I enter the camera control menu. Sorry, ref voltage is set to 3.30v.

bosbefok, 2019-10-27:
Is this something you can fix in the next update?

awolf78, 2019-10-27:
Not 100% sure yet, but we think we came up with a possible fix for this.

bosbefok, 2019-10-27:
Great. Let me know if I can assist in any way with testing.

SRWieZ, 2019-10-31:
I have a similar problem. My camera is constantly changing mode all the time whatever I do.
When I enter in a menu it constantly trying to go right. (in both menus, external and internal osd of the camera)

Board : Apex OSD
Camera : Runcam Micro Swift 3
Ref voltage : 3.2

bosbefok, 2019-11-08:
Hi Alexander, any progress with this issue?
I've noticed sometimes the mode is being changed now just when I open the OSD menu, even without accessing camera control menu. Doesn't occur every time but has happened on a number of occasions.

awolf78, 2019-11-08:
Unfortunately this is not going to be an easy fix since the chip does not behave like we were expecting. We have not given up on this yet, but a solution for this may take quite a bit longer.
As a workaround you can get a Runcam Camera Control board and set the camera control in the OSD to "serial". That will work for sure and not have any mode changes.

bosbefok, 2019-11-08:
Will setting the camera control to serial also disable the camera control functionality if it is wired for analogue? I've resorted to just pulling out the OSD wire from the camera for now, but if this is a way to do it in the OSD settings it would be better as I could enable when needed, and the disable once changes are made.

awolf78, 2019-11-08:
No, unfortunately not. The OSD wire from the camera must be connected to the Runcam camera control board for this issue to go away. Otherwise it is better to keep it disconnected.

AiroFpv, 2019-11-21:
Im having the same problem where it switches all the time. Running the johnny edition runcam. Still no fix?

awolf78, 2019-11-21:
Your best chance is using a Runcam camera control board and set the camera control output on the OSD to serial.

awolf78, 2019-11-28:
OK, possible workaround which works on the JohnnyFPV Runcam Swift Mini 2: Set the "Camera Sync" level to 200.
You can set the "Camera Sync" level in the GUI (click on the three stripes on the top left and then on Camera setup) or in the OSD menu (yaw left and hold for more than 3 seconds, SETUP->CAMERA CONFIG->CAMERA SYNC.

dweight, 2019-12-10:
I'm having the same issue with runcam swift micro v3 - your workaround helps but I can't change any settings now. This camera supports uart control is it possible to switch it on with the osd board? How should I wire it then?

awolf78, 2019-12-10:
Leave the wire where it is, but it to serial in the menu: SETUP->CAMERA CONFIG->CAMERA CONTROL and set it to SERIAL. You may have to change to serial mode on your camera as well, please check their documentation.

awolf78, 2019-12-30:
The preset switching issue has been fixed with V65.18 (not released yet when I wrote this). I am locking this conversation for others that may have the same issue. If you still experience issues with camera control, please open a new issue.

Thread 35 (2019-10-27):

Apex OSD no image no OSD

jesbombero, 2019-10-27:
The Apex OSD board I received when connected to camera and vtx, nothing is displayed in goggles. Channel is broadcasting but just grey screen, voltages from regulator are all correct and led lights show it is communicating with KISS V2 FC????

sblakemore, 2019-10-27:
Hi mate, this tracker is for issues to do with the ImpulseOSD firmware itself. For more general support requests or hardware problems can you please contact ImpulseRC support and they should be able to help with troubleshooting!

jesbombero, 2019-10-27:
Ok sure, thanks

Justin Smith

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

Closed 2019-10-27.

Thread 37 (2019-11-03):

Unify can not be configured

warp2, 2019-11-03:
Hi I can't configure my unify pro32 over OSD nor LUA script on the Taranis. Video is working with all other stuff (GPS, Battery...)
I have connected:
- 7-26V In (unify) to HV Power at the Wolf PDB
- GND to GND
- Video (unify) to Video Out at the Wolf PDB
- CRSF RX (unify) to VTX TX at the Wolf PDB
Any suggestion?
Or can I connect the CRSF RX to the Kiss as normally when having a setup without Wolf PDB?
Thanks a lot

awolf78, 2019-11-03:
Connect your Unify Pro32 to the TBS Agent and switch CRSF RX to SmartAudio.

warp2, 2019-11-04:
this did the trick, thanks for the tip

Closed 2019-11-04.

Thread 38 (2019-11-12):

Led Strip Not Changing Color

dsalexander99, 2019-11-12:
I installed the led strips provided with the apex frame and they only blink red. I cannot change the color through the apex osd.

awolf78, 2019-11-13:
Please read [https://github.com/ImpulseRC/OSD/wiki/Firmware:-LED-strip](url)

dsalexander99, 2019-11-13:
I’ve already read the info provided. I go thru the osd menu to led strip and try to change mode and color but nothing happens. It’s just stuck blinking red in the “knight” mode.

awolf78, 2019-11-13:
Can you post a DVR what you are doing?

dsalexander99, 2019-11-23:
https://www.dropbox.com/s/7y3exxyjwp1n5ge/Video%20Nov%2014%2C%208%2012%2021%20AM.mp4?dl=0

dsalexander99, 2019-11-23:
That’s a link to the video. Bare with me, I couldn’t get my dvr to record.

awolf78VDRS, 2019-11-23:
LED #1 is the one on the regulator board. LED #2-#7 are the ones that are in Knight mode. You need to select those and change the function/color for them

awolf78, 2019-11-23:
LED #1 is the one on the regulator board. LED #2-#7 are the ones that are in Knight mode. You need to select those and change the function/color for them

dsalexander99, 2019-11-23:
Thanks, I figured I was doing something wrong just didn’t know what.

Closed 2019-11-23.

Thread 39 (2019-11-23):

Won’t connect to configurator

mReXiTuS, 2019-11-23:
Hi Alex,

I was updating my wolf pdb with latest firmware and battery slipped out during process. Now I can’t connect to Impulse OSD configurator, it’s not recognized.

I tried shorting SDA and GND pins as you suggested in different threads, but it doesn’t work and I still have only green led.

However, I was able to enter DFU mode and DfuseDemo app can recognize DFU device, but I would need firmware file so I can re-flash it. Can you please send me something? Or is there any other way how to make it work? Afaik STM MCUs cannot be bricked and there is always way to reflash it either over DFU or worst case with STLink.

Thanks in advace.

sblakemore, 2019-11-23:
Hi,

Sadly we can't give you a copy of our bootloader to flash over DFU, I genuinely wish we could but we would have our code stolen if we didn't protect it.

If you can't flash it by shorting SDA and GND then you can ship it back to ImpulseRC and we will try to recover it for you. If you want to go that route please just open a support ticket with ImpulseRC.

Cheers

Closed 2019-11-23.

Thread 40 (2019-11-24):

No audio only SmartAudio

dsalexander99, 2019-11-24:
I can’t get any audio from the onboard mic. I have the unify pro 5v with the audio cable jumped across the audio and vtx control pad on the osd. I can control my vtx but I have no sound. Any ideas?

awolf78, 2019-11-24:
Do you have audio on any other quads you have that works?
Are you sure the volume on your goggles is turned up? Does the earpiece work you use?

dsalexander99, 2019-11-24:
Goggles are the FatShark attitude v5 which have the volume on high from the factory. The audio worked when I first built it then I ran into the problem that I couldn’t change vtx settings through my osd. So I jumped the audio and vtx pad and that gave me the ability to control my vtx but lost audio from the mic onboard. And yes I’ve tried different earbuds and they all work on other builds.

dsalexander99, 2019-11-27:
Am I just gonna have to choose between vtx control and audio ?

sblakemore, 2019-11-27:
@dsalexander99 this Issue tracker is really only meant for software bugs with ImpulseOSD. The problem you are having is not something which can be fixed in software.

You can try contacting ImpulseRC or TBS support directly as what you are trying should work fine and does for many people. Either there is something wrong with your hardware or there is something which can be fixed with troubleshooting via support.

TBS have a support page about this, it might be that you need to add a 100ohm resistor when bridging the pads. The 100nF capacitor is already on the OSD PCB. http://team-blacksheep.freshdesk.com/support/solutions/articles/4000100084-tbs-smartaudio-what-it-is-and-how-it-works

Closed 2019-11-27.

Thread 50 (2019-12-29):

PitMode 0mW setting not available

rauar, 2019-12-29:
I tried putting my VTX pitmode on a switch. The docs state I should choose 0mW but the lowest power setting is 25mW for me. The TBS UNIFY PRO 5G8 HV - RACE 2 supports SmartAudio 2.1 so that should not be the issue.

rauar, 2019-12-29:
I think I figured it out. I think the docs might not be up to date and it looks to me like they describe a former way of activating some kind of workaround pitmode. As pitmode seems to be a dedicated feature now in the menus the 0mW instruction looks obsolete to me. Right ?

awolf78, 2019-12-29:
Since older SA based VTX (SA1.0 through SA2.0) could only enter pit mode during power up I initially setup the PIT BOOT concept - pit mode could only be activated during plug in (VTX hardware except for the Tramp would support otherwise anyhow) and you can leave pit mode, but not enter it again. SA2.1 devices support a 0mW mode and if you set 0mW as low power (or set it to an AUX channel) it is equivalent to having pit mode on a switch. The documentation is up to date, but unfortunately I have created a little bug when I adapted my SmartAudio code for the RushTank VTX so it won't show the 0mW anymore.

Many thanks for reporting this, will be fixed in next release!

rauar, 2019-12-29:
@awolf78 i'm currently thinking about pit boot and pit mode on a switch back and forth. i think there are 2 setups from a conceptual point of view:

a) pit boot on one switch + low power setting (25mW)/high power setting on another switch
b) no pit boot, only power settings switch (currently with 2 levels)

the advantage of a) is that you will not by accident kill the vtx transmission by going into pit boot power level (0mW) after launch. the disadvantage is that you occupy 2 aux channels with this setup.

b) only needs 1 aux channel but flipping the switch when in high power mode will end up in 0mW which might be fatal as well during flight 🙈

At the moment my setup is a) which I'm ok with (safest setup IMHO and I still have a few aux channels left at the moment).

You wrote you will bring back 0mW as low power setting. That means if I enter 0mW as low power setting I can only switch between 0mW and x mW. I would recommend to introduce a third level here and allow each level to be configured in terms of power output (as it's possible right now). additionally the lowest power level is dedicated for pit mode and can only be entered again if disarmed.

I would configure this e.g. as this (for my taste):

low: 0mW -> pit mode when not airborne
medium: 25mW -> default power (from a legal perspective)
high: xxx mW -> high power (personally I just would only and especially use this for emergency cases to avoid a crash due to vtx failure)

Those 3 levels could be nicely mapped on a 3-level switch and entering pit mode 0mW by accident is impossible.

What do you think ?

rauar, 2019-12-29:
ps: on a side note: i noticed last week that pit boot only became active *after around 8 seconds* when powering on. this behaviour is gone since today and I think the cause was that I (still) had a VTX configuration for the band/channel in the KISS FC (althout vtx wires are soldered to Wolf PDB). I suspect that the Wolf PDB noticed that something is configured in Kiss FC for VTX and that it allowed Kiss FC to win the race. I guess this that was causing vtx power to be 25mW for the first 8 seconds which renders pit mode/boot in this time frame useless (might cause fatal noise for other pilots).

awolf78, 2019-12-30:
The power and VTX settings are synchronized with the KISS FC as long as DummyVTX or higher is selected on the KISS FC (DummyVTX is recommended). The advantage of the synchronization is that you can use LUA to change you channel/band and also low and high power levels (or KKC).
Due to the synchronization I like to keep it consistent and not differ from the KISS FC VTX settings.

Your argument with the AUX channels is not valid: Due to the configurable ranges you can use e.g. 3 position switches. PIT BOOT could be set to MEDIUM which can be the same as low power which could be on LOW+MEDIUM. High power would be set to high on the same AUX. Then you have all your VTX adjustments you want on one switch and AUX channel.

I personally have PIT BOOT on MEDIUM of my arm switch which happens to be a 3 position switch - but that's a matter of taste.

Closed 2019-12-29.

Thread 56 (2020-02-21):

OSD settings reset when removing battery

JohanJacobs, 2020-02-21:
Hi,

Not sure if this is the correct place to post.
when ever i unplug my battery all the settings on the Apex OSD resets back to default. (VTX channels and power, displayed items etc changes )
Even tried setting the defaults thru the PC software and through OSD.

setup :
Running ImpulseRC Apex frame
apex OSD and regulator
Kiss FC v2,
Johnny FPV camera
tbs unify pro 5g8 hv race2

thanks.

awolf78, 2020-02-21:
Try flashing with Full Chip Erase using the Windows GUI. In the GUI, click Update. Once you see the update screen, make sure Full Chip Erase is checked and select flash.

JohanJacobs, 2020-02-21:
Thank you,
update with Full Chip Erase selected fixed the issue :)

Closed 2020-02-21.

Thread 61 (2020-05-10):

Forgotten settings after a random number of packs

marcelkk, 2020-05-10:
I have the third Wolf PDB V3 now with the same issue: After a random number of power cycles (10-50 flights for example) the PDB starts and all settings are at the default values (OSD elements, VTX settings, battery...).
From this point the PDB only saves settings temporarily. I’m able to save settings at the begin of a pack, after power cycle it one time the settings are forgotten.

To Flash it with the GUI and „full chip erase“ will bring it back into normal working mode. But even then its a number of random packs again until the issue will start again.

6S Setup with 4x 470uF Low ESR Elkos (really well soldered and built well considered!)
Flyduino KISS V2
Flyduino ESC 32 A
Runcam Phoenix 2/Caddx Ratel (same problem with both cams)
Unify Pro V3 5V

awolf78, 2020-05-11:
At this point I need:

- Detailed pictures how everything is wired up on your entire build (Not only the OSD related stuff)
- Backup of your settings from the Windows ImpulseOSD GUI.

marcelkk, 2020-05-11:
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
I hope the picture explains everything you need!?
[2020-05-11_14-34-51_ImpulseOSD.faa.zip](https://github.com/ImpulseRC/OSD/files/4609711/2020-05-11_14-34-51_ImpulseOSD.faa.zip)

Vegetabondfpv, 2020-05-11:
Hello, I have the same problem as marcelkk.

I have already discussed the problem with marcelkk and we both cannot understand what could be the problem.

My 4s lipo setup

Wolf Pdb v3 (softmount)
Fettec F7 FC
4x 25A Kiss esc
TBS unify pro hv VTX
RunCam sparrow 2 pro
Crossfire nano Rx

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

awolf78, 2020-05-11:
Does this also happen when you flash V68.20?

marcelkk, 2020-05-11:
Yes, with both (V68.20 and V75.21)

awolf78, 2020-05-12:
Can you send me a backup of your KISS FC config also please?

marcelkk, 2020-05-12:
[kissfc-backup.txt](https://github.com/ImpulseRC/OSD/files/4616416/kissfc-backup.txt)
Sure!

awolf78, 2020-05-14:
You can try a beta if you want which will hopefully fix this issue (hard to find since I cannot reproduce it). Please post your MCU ID here so I can add you to the beta program. To get your MCU ID, press Ctrl+Shift+D in the Windows GUI and paste the contents of the Window that pops up here.
If you are on a MAC, go in the OSD menu (yaw left for more than 3 seconds) and go to SETUP->RESET. On the bottom of the Reset menu you will see a very long number - I need that including all the zeroes.

marcelkk, 2020-05-14:
I want to try everything that could fix it!

Device ID: 0047 7045 5547 7514 2032 2352

Is there any indication of what might be causing the problem? Please let me know if you're allowed to :-) For me it is also frustrating not to know whats wrong with my PDB/setup/whatever...
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

awolf78, 2020-05-14:
Please download and install the beta GUI from [here](http://osd-storage.impulserc.com/deploy-beta/setup.exe)

I added your MCU ID. Let me know how it goes.

marcelkk, 2020-05-15:
I flashed V79.23 and try it. I let you know if there are any problems. Thank you for the support!

awolf78, 2020-05-23:
I haven't heard anything so I am assuming this is fixed and I can close it?

marcelkk, 2020-05-23:
I would wait a few packs/flights more to be shure it’s fixed. In the past the failure happened after 4 weeks per example, so let’s wait a few weeks to be shure its really fixed. Until now everything is great 👌

marcelkk, 2020-06-04:
I think it’s time to say the issue is fixed!
No problem since flashing V79.23!
Thank you for the great support!

Closed 2020-06-04.

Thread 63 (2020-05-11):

SmartAudio v2.0 commands

slackista, 2020-05-11:
PDB v2, Unify 5V, 1uF cap between TX and mic.

Problem is why PDB is sending many packets to the vtx. According to
SmartAudio developers such implementation is wrong:
* at startup lots of packets (probing?) - wrong
* armed - one packet with increases power command - OK
* disarm infinity loop of commands - totally wrong

Startup: https://streamable.com/n3tr41
Arm and disarm: https://streamable.com/gp8owz

ImpulseRC support: "If your unhappy with any SA noise I would recommend using something with separate VTX control." - id est not our issue. Quite disappointing.

awolf78, 2020-05-12:
You could also solder the SmartAudio wire to your FC (KISS I guess) and from there a cable to the Audio on your Wolf or ApexOSD. Let me know if that improves your audio experience.

slackista, 2020-05-13:
Thank you for the suggestion. I will connect to KISS Tx5 instead of PDB.
Is SmartAudio VTX option in Kiss gui is fine with such configuration? Or interfering with ESC Kiss telemetry ?

awolf78, 2020-05-13:
KISS does ESC telemetry and VTX control on the same serial - no problem.

I have gone with a fine comb through my half duplex serial driver and smartaudio module - should be much quieter now. Will be a while until this hits a final release though, sending it to testers now.

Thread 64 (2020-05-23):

Complete reset on every pack after changing tune settings (BF)

udyux, 2020-05-23:
I've got the ApexOSD + regulator with a Holybro Kakute F7 V1.5 running BetaFlight 4.1. VTx is a Unify Pro V3 and cam is a Falkor 2. Been flying the setup since beginning of April with no issue.

Went out to fly after changing some stuff in my tune and started with a hot motor check. They were a little warmer than I'd have liked so I used the OSD tuning menu for the first time. I brought down my D term a few points and added a bit more D filtering. Flew the rest of the pack as usual.

When I plugged back in the SmartAudio kept making its usual racket for much longer than before until I got a message saying no connection to FC. I power-cycled and same thing until the OSD popped up but seemed to have been reset. Went into the menu to check the settings and hit Save and Exit it just said something like "Connection lost to FC 4"

Another power-cycle got the OSD back and I was at least able to set the VTx armed power. Flew two more packs and things work but when it's turned back on I have the set everything again.

In the meantime I'm going to see if the App Store download issue has been fixed and flash the firmware as I haven't been able to update it since I got the OSD board.

Thanks!

udyux, 2020-05-23:
Didn't really check the closed issues first. My bad. Will try downloading the Mac firmware flasher to see if I can flash to fix the issue.

Closed 2020-05-23.

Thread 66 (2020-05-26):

Can’t access Apex OSD menu in camera/ goggles

MJKitchin, 2020-05-26:
I have Impulse RC Apex Mr Steele quad. I have Foxeer Pred camera, Apex Osd, Kiss FCV2. I have been able to previously access osd menu using yaw left on Taranis X9d. Recently I was prompted in camera/ goggles to activate osd board and update osd via usb to impulse osd gui. I had activated and flashed to the latest firmware. I am now not able to access osd menu by yaw left on Taranis. On latest apex osd firmware update the red light remains solid, when I roll the firmware back to basics then the red light flashes. Either way, still no access to the osd menu in camera/ goggles like I was able to before. I have TBS Unify Pro Hv smart audio cable hard wired to Kiss FCV2 port TX5 and configured in Kiss GUI as always has been and worked this way before.

Any advice to resolve accessing Apex OSD menu again?

Thanks.

awolf78, 2020-05-26:
Try flashing with full chip erase.

MJKitchin, 2020-05-26:
I do not have an option on the Impulse RC GUI to 'Full chip erase'. I have followed steps of bridging SDA-GND, connecting lipo, removing bridge, connecting usb and GUI but no full chip erase option. Only firmware flashes.

awolf78, 2020-05-26:
Are you using Mac or Windows GUI?

MJKitchin, 2020-05-26:
Mac. I am guessing this is not possible on the Mac GUI. I do not have any windows.

awolf78, 2020-05-26:
When you say you "roll the firmware back to the basics": Do you mean you flashed a previous version? Or reset to defaults?
If you flashed a previous version: Which one is that?

MJKitchin, 2020-05-26:
I rolled firmware back one from v80... I still had a solid red light so tried rolling back to the bottom of the list. V1.1 and red light blinked as normal but still had no success with accessing osd menu, however, the ‘activate board’ message had disappeared from camera/ goggles. Flashing back to the latest firmware gives a solid red light and ‘activate board’ message appears again. I had never seen the activate board message before when I first built the drone. The message appeared for first time yesterday since I installed a new and the same Kiss FCV2.

Yesterday I installed impulse osd app on Mac for very first time as message wouldn’t disappear. Since then flashing to the latest firmware, the message disappeared for one battery test flight, then today had reappeared and will not go away even after re-flashing.

Unfortunately, I cannot see a ‘full chip erase’ on the Mac Impulse OSD gui. I am guessing this is a simplified gui version.

awolf78, 2020-05-26:
Unfortunately a Windows computer and Windows GUI will be necessary to fix this. Do you have access to a Windows computer?

MJKitchin, 2020-05-26:
Hi, I thought this might be the case. Unfortunately, I do not have access to a windows computer or windows GUI.

sblakemore, 2020-05-27:
Sorry, we have a new Mac GUI in development which we plan to be full featured, but that will some time before it'd ready. The only way to fix this at the moment is to find a Windows machine you can borrow for a short time, or install a trial of Windows in Bootcamp.

MJKitchin, 2020-05-27:
Hi all, thank you for your replies and advice on this matter. I managed to source a windows computer and fixed the issue quickly with the steps outlined for ‘full chip erase’. Thanks!

sblakemore, 2020-05-29:
Happy to hear you got it fixed! Hopefully we can have a nice Mac GUI for you fairly soon :)

Closed 2020-05-29.

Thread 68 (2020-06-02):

Apex regulator board - losing power to KISS FC

udyux, 2020-06-02:
The issue may be unrelated to the Apex regulator board but I figured I had nothing to lose by checking here if anyone has a clue. I've posted recently about a Holybro Kakute F7 setup but have since switched to a full KISS stack.

Maiden flight 2 days ago went well except that I hadn't set up the FC correctly to enable Airmode. I opted to go with the Idle Up approach based on a video Steele made about a year ago. Second flight, yesterday, ended after 50s. [Here is the DVR recording (volume warning)](https://streamable.com/a9wx1f), crash happens at 0:52.

Everything seems to indicate a loss of power to the FC just as I initiated a snap half forward pitch/half roll (lookback). ESCs were beeping out of sync after the crash but were beeping at a rate of 2/sec, indicating ESC failsafe. OSD was displaying alternating "No connection to FC 4" and "Telemetry lost" messages. Both the FC and OSD are powered via the regulator board and the OSD was still running after the crash. I also noticed that the OSD timer stopped counting the moment the quad seems to lose control but stays visible up until I hit the ground (which is when I would have disarmed).

I was able to reproduce these symptoms by arming the quad on the bench and pulling the Regulator/FC/OSD plug from the FC.

Setup:
ImpulseRC Apex frame running 4S
KISS FCF7 V2 [1.3RC40o]
KISS 4-in-1 ESC [latest stable]
Apex OSD [latest stable]
Apex regulator board
Foxeer Falkor V4
TBS Unify Pro 5G8 V3
Apex Hornet 2306.6 2555KV motors

It was built following Steele's build video, so the ESC is inverted and rotated and the FC is mounted on 7mm rubber standoffs. The wires are routed between the FC and ESC as he demonstrates but I have since noticed the tip in the docs concerning this.

Worth noting that I couldn't get my hands on the official ImpulseRC 3-way wiring harness for the Apex gear. I have a ton of pre-crimped JST-SH wires and connectors that I've used numerous times in the past and made my own harness. I figure I got the wiring right since the quad flew and I carefully followed the various wiring diagrams and used an image of the official harness as reference.

The SH plugs seem to be held in place by the pins and crimps, since placing an empty connector into a socket doesn't hold on its own. I'm going to try replacing the Gnd/VCC wires between the regulator and OSD but any other troubleshooting tips are more than welcome.

udyux, 2020-06-02:
Quick follow up question. There is very little mention of the pads on the regulator board in the docs.

If I want to eliminate the connector and regulator board as the source of the problem should I try simply soldering the VCC pad on top of the regulator board to the lipo positive on the FC and one of the LED grounds to the lipo negative on the FC?

awolf78, 2020-06-02:
The Apex OSD harness passes through Lipo voltage to the FC - so not regulated voltage.
For your case I would completely eliminate the ApexOSD and Apex Regulator. Not saying it has anything to do with your issue, but then it may be easier to pin point what the issue is. It may also be a connection issue. I would just keep the the ESC connection to the 4in1 ESC and pull separate wires to supply Lipo voltage to the FC. Good luck.

udyux, 2020-06-04:
As suggested I soldered wires straight from the 4S input to the FC. Flew several minutes over grass without issue, it waited for me to be over concrete this time before giving out.

This build has drawn its max out of me. Months now and I still can't go 4 packs without it falling out of the sky, regardless of the stack I put in it.

Closing this issue since the one thing I do know now is it's not a connection issue with the Apex regulator.

@awolf78 Thanks for always being so responsive and patient with all of us. Class act!

Closed 2020-06-04.

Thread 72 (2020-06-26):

Windows GUI connection issues

awolf78, 2020-06-26:
For all of those who are experiencing connection issues with the Windows GUI:

1. The GUI uses the Microsoft HID driver to communicate with ImpulseOSD boards. On some installations the HID driver does not act as expected and can cause connections issues.
2. It seems to matter in which order you are connecting the Lipo, USB cable and start of GUI. If you experience issues, try different combinations.
3. The combination that seemed to work the best on first plug in: Plug in Lipo - wait 5 seconds. Plug in USB - wait a few seconds and watch if Windows is installing any drivers - wait until that is complete. Start GUI.

jayboy120, 2021-01-21:
Have tried everything and still cannot connect to wolf v3 osd on windows 10.

even tried the recovery process youve listed by soldering the sda and ground pads. tried that process several times and the red light just stays solid red.

anything else i can try?

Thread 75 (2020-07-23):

Apex OSD mAh consumption value jumps by thousands

udyux, 2020-07-23:
I've already got a pretty good idea of what's causing the problem but figured, for posterity's sake, I'd open an issue in case I'm either wrong or someone else is experiencing the same behaviour.

The drawn mAh value will jump multiple thousands, eg. from 450 to 24000 in an instant. Seems to only occur on snap flips. Running the Apex OSD, latest FW, with the FETtec FC and the Flyduino 4in1 ESC.

My theory is that the data is being corrupted by EMI from the ESC as I am running the telemetry wire under the FC. I'll be routing it over the top to see if it helps.

Do with this issue as you see fit, I just thought it was worth mentioning.

awolf78, 2020-07-23:
If you have telemetry on your radio, you can actually narrow down if the issue is generated by bad telemetry data or the OSD. If the radio shows the same crazy value as the OSD it is due to the EMI you are suspecting (and me too BTW).

udyux, 2020-07-28:
I do have telemetry setup on my R-XSR, I'll have to look into how to get the readout as I've never really used it for anything other than RSSI.

My theory is drawn from the Flyduino FC shutdown issue I was having which turned out to be caused by running 4S with the Flyduino 4in1 mounted inverted (FETs facing up). A couple of us had the same issue with identical setups which was resolved by flipping the ESC back over. In my case the problem was happening on snap flips, as is the case with the OSD.

I'm waiting for my TX16S to arrive so I can finally make the switch to Crossfire which is when I'll try re-routing the wires, dont really feel like opening up the quad as it flies perfectly otherwise. I'll check the telemetry in the meantime.

udyux, 2020-08-10:
I've routed the Tx/Rx telemetry wires that link the FC and OSD on top, away from the ESC. After at least a dozen flights I can report that this seems to have resolved the issue.

Closing given the positive result.

Closed 2020-08-10.

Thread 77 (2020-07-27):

OSD Gone when armed

Paulson21, 2020-07-27:
Hello, hope everyone is staying safe. I love my apex, I have the Mr.Steele version.  I flew about 20 batteries with the stock settings not realizing my VTX was at 25mW. Once I switched my VTX to 500mW, my OSD is gone when the drone is armed.  OSD comes back when the drone is not armed. Did a full erase on the Apex OSD board and updated to the newest version available non beta. Problem still exist after all updates, It did work one time before I touched/changed any settings at all in the OSD. I just find it weird I flew over 20 flights with no issues and a VTX(Team Black Sheep Unify) made my OSD gone when armed now. Both ground wires (VTX and Camera) are on the same GND pad.

Please let me know what I am doing wrong. Thanks for all the help in advanced.

awolf78, 2020-07-27:
Since you have a Mr. Steele Apex, I assume you are using the Apex Regulator board powering the Apex OSD. I also assume you have the standard wiring harness between ApexOSD, Apex Regulator board and KISS FC?
If all my assumptions are correct: Try measuring the 5V on the ApexOSD (and 7.5V output on the Apex Regulator) when setting the disarmed power to e.g. 500mW. Let me know what the voltage meter says.

Paulson21, 2020-07-27:
Yes I am using the Apex Regulator. I am using the supplied wiring harness that came with the kit.

The voltmeter showed me 5.05V and 7.2V

awolf78, 2020-07-27:
Ok, what VTX model are you using (5V Unify?) and what camera? Is the + of the camera connected to 7.5V or 5V? What about the VTX?

Paulson21, 2020-07-27:
Team Black Sheep 5V Unify Pro 5V V2 soldered to the 5V pad.
Steele Swift Mini 2 soldered to the 7v pad.

awolf78, 2020-07-27:
Set the camera sync to 200.

Paulson21, 2020-07-27:
That makes the OSD distorted and jumpy

awolf78, 2020-07-28:
At this point I would need to see a DVR what exactly is happening when you arm the quad.

blackdrone911, 2020-09-12:
Hello,
I have a similar problem. Only that my OSD flickers during the flight and disappears sporadically, so that i can't see the telemetry datas. Also during landing and when disarmed, sometimes the OSD cannot be accessed.
What could I check?

Used component:
KISS FC v2
Wolf PDB OSD v3
KISS 32A ESC
TBS micro TX v2
TBS nano RX v2

blackdrone911, 2020-09-12:
Hello,
I have a similar problem. Only that my OSD flickers during the flight and disappears sporadically, so that i can't see the telemetry datas. Also during landing and when disarmed, sometimes the OSD cannot be accessed.
What could I check?

Used component:
KISS FC v2
Wolf PDB OSD v3
KISS 32A ESC
TBS micro TX v2
TBS nano RX v2

blackdrone911, 2020-09-12:
Hello,
I have a similar problem. Only that my OSD flickers during the flight and disappears sporadically, so that i can't see the telemetry datas. Also during landing and when disarmed, sometimes the OSD cannot be accessed.
What could I check?

Used component:
KISS FC v2
Wolf PDB OSD v3
KISS 32A ESC
TBS micro TX v2
TBS nano RX v2

blackdrone911, 2020-09-12:
Update,
seems that (for the moment) I solved the problem via setting Camera Sync.
But two question are open for me.
What is Camera Sync? It was setted to 0
Why I can do this setting only through the google and not in the Software (KISS, ImpulseOSD)?

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

awolf78, 2020-09-12:
You can set it in the ImpulseOSD GUI. Click on the 3 stripes on the top left and then on "Camera".

blackdrone911, 2020-09-12:
> You can set it in the ImpulseOSD GUI. Click on the 3 stripes on the top left and then on "Camera".

Yes thanks, rly stupid from my side. I got it!
But what does this value mean? And what’s the best “fitted” value?

awolf78, 2020-09-12:
It changes the synchronization level for the OSD and depends on your camera. Most cameras work fine at the default 0, some need 100, some 200. If you do not get any flickering and your OSD does not vanish then you are good and don't need to touch the value any more (keep it at 200).

blackdrone911, 2020-09-12:
> It changes the synchronization level for the OSD and depends on your camera. Most cameras work fine at the default 0, some need 100, some 200. If you do not get any flickering and your OSD does not vanish then you are good and don't need to touch the value any more (keep it at 200).

Ok! I got! Thanks a lot for the reply, that solved my problems!

nipponbike, 2020-09-22:
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

same configuration -same problem : after 2 or 3 packs loose of OSD...have to disconnect an dconnect together

awolf78, 2020-09-22:
Try raising the camera sync to 100. If it still disappears, raise further to 200.

blackdrone911, 2020-09-22:
Yes exactly this helped me, thanks again!
Nipponbike take a look at the older posts. I am sure this will solve your problem.

nipponbike, 2020-09-30:
raise to 100 .....same problem, raise to 200 -totally loose of OSD ! - even the whole image disapears sometimes....  (need to connect the lipo a second or third time to get my image back) Is that PDB  broken ???

awolf78, 2020-09-30:
OK, try flashing with "Full chip erase". If that doesn't help I would need to see your wiring.

nipponbike, 2020-10-10:
Full Chip Erase did not help , same issue, it happened more with 6S than with 5s batteries...., but i´m done with that PDB...

nipponbike, 2020-11-01:
> OK, versuchen Sie mit "Full Chip Erase" zu blinken. Wenn das nicht hilft, müsste ich Ihre Verkabelung sehen.
Sorry, the Wolf_PDB is OK !!! , but this PDB is definitive not compatible with a CADDX Ratel-Camera !  I switched back to my RuncamSwift-Mini and everything works well !!! Thank you !

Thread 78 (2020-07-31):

Many serial communication errors occurred

ebeez, 2020-07-31:
Hi,
I am getting this error once I connect tot he FETtec configurator and click on the telemetry button settings button. I can connect fine and see all 4 ESC's in the overview. I plug in the micro USB cable first, open the configurator, plug in the Lipo and then hit connect. All fine at that point. As soon as I click the telemetry or setting button i get a series of beeps and then the error in the subject line

awolf78, 2020-07-31:
Sorry, but this issue has nothing to do with ImpulseOSD related hardware. Please contact FETTEC support about the issue with the ESCs you are having.

Closed 2020-07-31.

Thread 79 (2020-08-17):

OSD Jumps around and will not save RSSI settings since switching to CRSF

udyux, 2020-08-17:
I've been flying for the last few months without any issue using the following equipment:

- ImpulseRC Apex with FETtec F7 KISS FC & Flyduino 4in1 25A ESC (running 4s)
- Apex regulator & OSD boards
- TBS Unify Pro 5G8 V3 & Foxeer Falkor 2 mini
- FrSky R-XSR receiver

As of yesterday, I finally have a Crossfire Micro TX V2 and installed a CRSF Nano RX in my Apex. Two problems have appeared since:

1) The OSD jumps around on the screen ([short clip of the issue](https://youtu.be/PGmwSuXWeDY)).

2) When I change the RSSI setting on the OSD and set it to CRSF+LQ preset and save+exit, it doesn't seem to save it. This is without a power-cycle or anything. Just save+exit, go back and it says "Custom"

Just to be clear, the only change since this started is swapping from FrSky to CRSF.

I've flown 7 packs so far, updated my OSD to the latest version, changed the VTx channel, all with no change.
My KISS FW is `1.3RC45y` and my Crossfire TX/RX is running `v3.75`.

awolf78, 2020-08-17:
1. Set the camera sync to 100. That should fix the jumping OSD issue.
2. Assuming you have 40o or higher on the FC: Leave the RSSI setting on "AUTO" (Defaults). It will pick up the CRSF data automatically and set it up appropriately.

udyux, 2020-08-17:
Thanks I'll give that a try and report back.

Another thing I noticed was that I could hear the SmartAudio clicking for much longer than before. Don't know if it's related.

Any idea why this might have started at the same time as making the switch to CRSF?

udyux, 2020-08-19:
@awolf78 I've set the camera sync to 100 and tried again to set the RSSI to auto. Just to confirm, this was happening before and after I updated the OSD FW to the latest version. I also noticed all my settings had been preserved after the update, not at all a complaint but wasn't sure if this was supposed to be the case.

**Result:** the flight OSD no longer jumps around however the OSD menus and temporary labels like "armed", "disarmed" or quick battery selection have started glitching.

As for the RSSI, at the end of the following clip you'll see me try to change settings in the RSSI menu. Every time I set the preset to CRSF and come back the preset has reverted to "custom" and even with the custom mode selected the only value I can change is the AUX channel, the rest of the settings change for split second and go back the the value it was at. Is this the expected behaviour?

[Video link](https://youtu.be/NCLziZDWYlA)

There are two other issues since I swapped from FrSky R-XSR to the TBS Crossfire Nano RX:

1) As mentioned in my previous comment, the SmartAudio clicking sound when I arm and disarm (probably to change the power level) goes on for much much longer than before. It used to give two clicks consistently. You can see what I mean when I disarm in the video.

2) I've started seeing faint black lines in my feed when I hit the throttle which wasn't something I'd been seeing before. You can see them at the very start of the video and also when I touch down and theres a small blip of the throttle before I disarm. From my understanding this is usually power related but I seem to recall seeing somewhere that excess D-gain can produce similar video banding. Nonetheless, last time I changed my tune was long before switching to Crossfire.

For reference I've been running the VTx at 800mW. Maybe also worth noting is that the receiver is mounted on top of the Apex regulator board with double sided tape (as was the R-XSR) and is installed exactly as Steele mounts his in his build video (with the excess antenna lead held down under the receiver).

I'm a bit baffled by the fact that switching to Crossfire could introduce these kinds of issues but I've literally not changed anything else on the quad.

awolf78, 2020-08-19:
RSSI/LQ settings: Leave them as they are. When the RSSI channel is on "AUTO" you cannot change the other values. On "AUTO" it configures everything automatically and grabs the CRSF LQ information automatically from the KISS FC. You don't have to do anything, your LQ is displayed properly in the OSD and it barely drops below 100% unless you start flying a few km out or fly behind objects (careful).

Video glitches: The cam sync of 100 seemed to have helped, but judging by the video you may need to go higher. When you change the value in the OSD it is applied immediately. If you go up and it starts jumping more - go down. Try to find the minimum and maximum value where it starts to get worse and then set it in between. Then you should be fine overall.

SmartAudio:
I literally had the same experience on my own quad. But I did not change anything on the quad, all I did was open it and put it back together. The SmartAudio communication is not the most stable and moving the wires a little bit can cause interference - then it needs a few more tries to make sure the command got through to the VTX.
Keeping the wires very short and making sure they are routed away from any possible should improve this.

Black video lines/noisy video:
This is a known issue with the Fettec FCs and may require some re-routing of the grounds. Can you give me a short description how you have it wired up along with some pictures?

Change from FrSky to CRSF:
To be honest I have no explanation why you are having all these issues where you had none before. I can only point to the known grounding issues related to the Fettec FC. For some reason those did not show up when you were on FrSky. Possibly the change in amperage draw from the FrSky Receiver to the CRSF receiver had an effect on this.

udyux, 2020-08-19:
Thanks for the detailed response @awolf78, staying true to ImpulseRC's "above and beyond" mantra as always! I suspected that some of my issues were unrelated to the Apex PDB/OSD so thanks for taking the time to share your insights.

**RSSI**
Ok, reassuring words.

**Video glitches**
I'll try calibrating this and let you know which number did the trick for future reference.

**SmartAudio**
Makes sense, I've got the VTx mounted to the top plate above the camera/OSD just in front of the FC. The wires are already quite short, I often tug on them with the top plate in hand before removing the connector. I noticed yesterday that the OSD 5V  and GND to the VTx seemed weak at the joint. To be safe I replaced both wires and did a better job on the joint.

I have all VTx and camera wires neatly tucked in between the camera and the OSD board. We'll see if there's improvement since changing those two wires.

**Black lines**
I'll see if I can get some pictures after work but I haven't done anything fancy. For clarity, I'm running FETtec FC with Flyduino 25A 4in1 ESC. I'm running 4S with no cap.

I couldn't find the ImpulseRC OSD/PDB wire harness in stock anywhere but have a bunch of pre-crimped wires and made one. Wiring:
- 8 pin connector under FC to 6 pin connector on ESC (last two slots on FC plug are empty - GND / VCC)
- ESC LiPo pads feed 2x VCC and 2x GND to the PDB
- 7.5V, GND and LED wire running from PDB to OSD connector (routed _beneath_ FC)
- VCC and GND going from PDB to connector on top of the FC
- RX/TX from same FC connector as above to OSD connector (routed _above_ FC)
- GND pad on OSD is shared by camera and VTx
- 7.5V, Video in and Cam control from OSD to camera
- 5V, Video out and audio/SmartAudio (bridged) to VTx

Not that I think it will make a difference but the Nano RX is wired to the connector beneath the FC. When I first wired it up I had inverted the TX/RX wires. Only trouble it seemed to cause was no control received by the FC until I swapped them.

awolf78, 2020-08-19:
Try running the "7.5V, GND and LED wire" above the FC.
If I understand this correctly, the FC is powered and grounded by the Apex Regulator Board (you call it PDB) ONLY. There is no (direct) GND between FC and ESC?

udyux, 2020-08-19:
Yeah, I get tired of writing regulator haha. Ok for the regulator -> OSD harness.

I though I was thorough yet the only detail I left out is the only one that mattered! There is a GND between the two on the ESC -> FC harness. The last two on the FC are empty as mentioned, but the 6 others are motors 1-4, Telemetry and GND.

awolf78, 2020-08-19:
Ok, lets see if moving the wires above the FC helps you. If it doesn't, the next step would be to remove the GND between Apex Regulator and FC and add a GND between FC and Apex OSD (any GND pad on both sides works).

udyux, 2020-08-20:
After routing the regulator/osd wires over top I tugged on the VTx wires by accident and the audio/SA wire came loose. Naturally I replaced it.

I don't know if it made a difference but I'd read in the past that twisting video and GND can help shield a bit. So I twisted the SA, Vid and GND to the VTx together.

When I plugged in, without making any changes to camera sync, everything looked good in the menus!

So for the jittering menus either routing the wires over the fc, twisting the signals and GND, fixing a weak joint or some combination of these resolved that issue.

I'll have time to fly after work so I'll see for the black lines and SA clicking. I'll also try putting the sync back to 0 to see what happens.

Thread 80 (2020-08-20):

GPS not working

dizzy32141, 2020-08-20:
Im really having a hard time to get my GPS to work on my Wolf PDB + KISS V2 build.
I bought a M8 GPS from TBS about 2 Months ago.
It worked on an older Version of KISS and WOLF PDB but then it stoped working someday. At first I didnt realize it.
All I did was updating KISS and WOLF PDB till now but I never got it to work again.
So I thought the GPS may be defect and bought a Matek M8Q-5883.
Soldered it on the PDB and got the RED and Blue LED on the GPS but nothing on my OSD!
I checked the wires with a multimeter, nothing wrong.
I double checked the wiring and also soldered on different 5V, TX, RX and GRD pads.
Then I also noticed that my quad does not double peep like usually anymore after I plugged my battery in.
So something must be wrong but I dont know what it could be.
On the Wolf PDB there is a green light with a flashing red light (should be normal i think).
I can arm it normally but no GPS in OSD and no peep before start anymore (tested with and without GPS).
The OSD shows only the compass but its only flashing.
Please let me know what I possibly did wrong or if there is a defect or issue with the firmware or something.
I really dont know what to do anymore. I attached some photos and videos. Please excuse my bad english. have a good day

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

https://youtu.be/ZB6Eq6Xg9vs
https://youtu.be/r5Zh2EjeMVg

awolf78, 2020-08-20:
Please swap the RX/TX wires on the PDB. RX(GPS) goes to TX(PDB) and vice versa.

dizzy32141, 2020-08-20:
Swapping the wires solved it! Also got a double peep now after reconnecting the LED Stripe! Thanks a ton man!

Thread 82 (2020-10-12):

Add support for NEO-M9N

slackista, 2020-10-12:
Add support for new ublox chip NEO-M9N to take advantage of its full potential.

awolf78, 2020-10-12:
Have you seen any commercially available boards yet for the M9N? That fit on a 5"-7" mini quad?

slackista, 2020-10-13:
After ~two weeks we should able to buy Matek M9N-5883 for $45. Size and weight is affordable for 7".

slackista, 2020-10-17:
https://store-drotek.com/917-DP0801.html

slackista, 2020-11-02:
There are now plenty of stores with NEO-M9N. Does current firmware support UBX-NAV-PVT messages?

awolf78, 2020-11-02:
I'm still waiting on mine to show up in the mail. I may add a 25Hz mode if it works reliably.

slackista, 2020-11-20:
To be clear, NEO-M9N not working with latest firmware v86.25

slackista, 2020-11-24:
I received my neo-m9n and is working fine with v86.25 latest firmware. I've got 16 satellites in big city after one minute cold start. Closing that issue.

slackista, 2020-12-13:
Reopening issue. Mine M9N sometimes dropping satellites to LOW count. Same behavior when I chose setting `used`(GGA max 12 satellites) or `available` in gps settings. Such issue can cause rth drop. DVR presenting issue: https://streamable.com/d88hcv

awolf78, 2020-12-13:
If you post your MCU ID here (press Ctrl+Shift+D in Windows GUI) I can give you a beta version you can try. That will also allow to run the GPS at 25Hz (instead of 10Hz).

slackista, 2020-12-13:
Sure. Device ID: 0023 302F 5534 4507 2032 2339

awolf78, 2020-12-14:
I added your MCU ID, please use this link for the beta GUI: [Beta GUI](http://osd-storage.impulserc.com/deploy-beta/setup.exe)

awolf78, 2020-12-21:
Have you tested the beta? Did you try with 25Hz? Does RTH work on 25Hz?

slackista, 2020-12-21:
Haven't got time yet to test. I have beta firmware on 7" now, so probably I would not test RTH with 25Hz on it. To heavy in case of drop. For sure I will test 25Hz flying and 4 GNSS systems simultaneously. Probably on this Sunday.

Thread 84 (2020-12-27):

OSD cell voltage & weird behaviour

dizzy32141, 2020-12-27:
I was testing my 6s Li-ion battery and had a little crash were one of the crossfire antenna went off.
I didt'n notice it at first but after another flight with a normal 6s pack  I went indoor and replaced the antenna.

After replacing I went out and flew another 6s Li-ion pack. I noticed that the cell voltage in the osd was completely off.
It showed me a value between 4.20 and 4.40.
I was very confused because only if I plugged in the Li-ion batterys, the value was wrong. If I plugged in a normal and uncharged Lipo the value was correct.
I reflashed the FC, the OSD and the ESC but the problem persists. I reseted the telemetry data in the taranis but in the taranis the values are correct.  I charged the Li-ion batterys and the cell voltage was correct again. But everytime I connect a uncharged Li-ion battery it gives me a wrong value in the OSD.
Is it because of the low voltage of the Li-ion, a bug or is anything broken?

Then a flew a pack to test if its safe flying. The cell voltage is ok until I plug an empty Li-ion battery in. But now I had massive OSD flickering till the OSD was completely gone. I set the camera sync to 100 and it fixed the issue.

Now everything is ok except the stats of my CRSF-link and the timer shows no symbols anymore. Its just a black box were the symbol normaly is. Here's a screenshot:
https://ibb.co/89HJ20F

Could you please tell me what is causing the black boxes and the cell voltage thing? Thanks man!

awolf78, 2020-12-27:
Please flash your OSD again with "Full chip erase".

dizzy32141, 2020-12-27:
I flashed the OSD with full chip erase but the black boxes are still there. Do I have to do a downgrade first? I noticed that after flashing the OSD, I have to update the Impulse OSD Logo that appears at startup. If I dont update the logo, its like one big black box instead of the logo at startup.
Here's a screenshot: https://ibb.co/KrYLmnN

awolf78, 2020-12-27:
Hm, if you flash with full chip erase it does write the default font completely new and all those black boxes should disappear. There is a possibility for a defect on you OSD board. Please contact your dealer - it is up to them how to handle this situation.

krunked-fpv, 2020-12-27:
Have him do the rescue flash where u solder the pads with a wire and snip
it.  Worked for me.

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

awolf78, 2020-12-27:
> Have him do the rescue flash where u solder the pads with a wire and snip it. Worked for me.

That only forces the bootloader so you can flash in case the firmware got corrupted somehow or cannot start.
The OP has a different issue, something is going wrong during flashing or he forgot to click the "Full chip erase" button. If Full chip erase does not help the STM chip on his OSD board may be defective...

dizzy32141, 2020-12-29:
Thanks guys! Today I will rescue flash just in case and if its not normal after flashing I probably will use this PDB in my freestyle quad. What do you think? It's safe to fly like that?
I also have a broken PDB V3 here, were a solder pad went off. What about replacing the STM Chip from this old board?

awolf78, 2020-12-29:
After you flash with "Full chip erase" make sure you leave the Lipo connected for a minute or two. It rewrites the font and if you unplug the Lipo during that time these issues can happen.
If the board that is giving you issues is also a PDB V3 you can swap the STM chips if you feel comfortable doing that.

dizzy32141, 2021-01-02:
Hi Im back. Tried to full chip erase but my device is blacklisted now. I tried 5 times or so before. Still need to try it with lipo plugged in for a few minutes.
Device ID:  https://ibb.co/4dWxrkh

awolf78, 2021-01-02:
Removed you from the blacklist.

dizzy32141, 2021-01-04:
So I did the rescue flash and full chip erase properly. No improvements but I will use it in my freestyle quad then. Thx for the great support and have a good one guys

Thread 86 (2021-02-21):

Font not changeable + missing signs

blackdrone911, 2021-02-21:
Hey!
1. Why it’s not possible to change the OSD font? It’s shown in the GUI but in the goggles  it’s still the basic font.
2. Also there are some signs missing. Instead of °C you can see there 2 big black bars. The same you can find in the statistics when disarming the quad.
How I can fix that?
Full chip erase I tried 2 times without any solution for both problems.
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

awolf78, 2021-02-21:
Please flash again with Full Chip Erase. IMPORTANT: After you have flashed (and clicked OK to go back to OSD setup screen in the GUI), keep the Lipo plugged in for another 20-30 seconds. During that time it flashes the font again. Then the characters you are missing will be shown correctly.
Font: Can you show me how you are doing that? In a video?

blackdrone911, 2021-02-22:
ok now it looks much better! Now there is only a black bar in the picture but we are making progress!
Attached is the video, but I think you can’t do something wrong there. Finally this is working too!
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
![Uploading DDFE0278-88D8-4AB9-A083-AA970B3A41DE.jpeg…]()

awolf78, 2021-02-22:
OK, looks like the font changes accordingly.
The black bar in front of the (MCU) temperature should also have been fixed by the full chip erase method - you can try again and wait after it restarted. There should be a small square box with white legs that looks like a MCU when the font is correctly loaded.

blackdrone911, 2021-02-22:
I tried 3-4 times after I got tired. Tomorrow I’ll try to flash the old software than the newest one, maybe this helps?

blackdrone911, 2021-02-23:
So, now the PDB is blocked after several full chip erases. What now?
![Uploading 33ABE8CA-F724-4566-A970-1EAA209B485F.jpeg…]()

awolf78, 2021-02-23:
Post your Device ID here - or if you do not feel comfortable doing that open a support ticket with ImpulseRC. They will unblock it for you.

blackdrone911, 2021-02-24:
Ok, here is the image with the ID.
Is there another method the get the bugs out instead of full chip erase?

![Uploading 8BCA40F1-2906-432C-8B2C-2DC9B8F0B828.jpeg…]()

awolf78, 2021-02-24:
I removed your device from the blacklist.
I am guessing it is only that one character next to the temperature that has that issue? The only way to fix that is with a full chip erase, but since you have done this multiple times already and it did not help I can only assume that this part of the flash on you chip is defective. You can present this case to your dealer, but it is up to them how to handle this.

blackdrone911, 2021-02-24:
Nah, it’s nearly new :)
So, now it’s done! Seems that the downgrade helped me out! Everything looks as it should! Great, I am fine again! Many thanks for the support!

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

Closed 2021-02-24.

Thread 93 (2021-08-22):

OSD completely disappears

udyux, 2021-08-22:
I have 3 nearly identical Apex. All have the FETtec F7 and 45A (except one with the Flyduino ESC) running 4S, regulator board, Apex OSD, Unify 5V V3, Falkor V2. Both the FETtec ESC builds have spike absorber and cap. All have same/latest FW and identical configs.

All are wired up the same with an additional ground running from the FC to the ground pad on the mic side of the OSD. All wires run above the FC.

On one build (45A ESC) the OSD completely disappears on throttle punches or sharp moves. At first it would only happen on 1/5 packs but lately it's on every pack. Power cycle brings it back (but it's lost consumption from before the power cycle, doesn't ask if I want to continue the last battery). I also noticed the "heartbeat" LED on the OSD isn't blinking anymore when the OSD is gone but the other lights are still on.

It's never happened on the two other builds. Any ideas?

awolf78, 2021-08-22:
How is the FC connected to the ESC? With the wire that came with the ESC? In that case remove the VBAT between FC and ESC. You are already getting VBAT from the regulator board to the FC.

udyux, 2021-08-22:
I've got the FETtec 45A feeding the FC and pulled the VBat and Gnd from the regulator harness to the FC. I've done this on both of the builds using that ESC. Could this be the cause? (Haven't experienced the issue on the other)

awolf78, 2021-08-23:
You need the GND from the ESC to FC - but remove the VBat between ESC FC.

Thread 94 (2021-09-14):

OSD board overheating then video doesn't work

Elodin12, 2021-09-14:
I recently had a minor crash and the video cut out on my apex. after the crash, I could see the video and the osd boot logo, and then in about 10 seconds the video would kinda waver and said out to black. when I checked the connections all the wires had a solid connection but the big chip next to the microphone (I think it's the voltage regulator or something)would heat up to untouchable temperatures in a matter of seconds. The osd also said it did not have a connection to the FC on startup. I tried the rescue flash after resoldering all the connections just to be sure. Now I don't even get those few seconds of video I had just after the crash. Any idea how I could go about fixing this or should I just contact who I bought the Apex from to see if I can get a replacement? Thanks

Elodin12, 2021-09-14:
Is it possible to connect the yellow cam wire to the vtx directly to make sure that I diagnosed the osd as the problem Apex osd board?

sblakemore, 2021-09-15:
Hi, if the voltage regulator is overheating and shutting down this is usually caused by a short somewhere which is drawing too much current for the regulator to handle.

This github is for software issues though, for hardware support please contact ImpulseRC directly.

Closed 2021-09-15.

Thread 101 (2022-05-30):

ELRS and Apex OSD

Linuxbarista, 2022-05-30:
Has anyone tried getting the RSSI or LQ from ELRS to work in the OSD? I've tried doing the "old method" of putting a telemetry sensor (1RSS) data on an input channel of the radio and pushing that to a mixer channel. I can't seem to get it to read out correctly.

Hoping there is a guru here that can explain what min/max PPU I should set and what I'm doing wrong on the radio input mixer side? Basically followed Bardwell's method from a couple of years ago. https://youtu.be/t-evOAS9Mkg I do know that ELRS runs from -128db - 0db. I'm not too familiar with how FRSky RSSI works. I believe it's 0db - 100db. I did try playing with different "scale" and "weights" on the inputs. Also tried playing with the "weight" and "offset" in the mixer section. I got it working somewhat but it wasn't very accurate. I know ELRS is outputting RSSI or DB on AUX 12 and I believe LQ is on  AUX 11.

I'm guessing this is prob not going to be possible until channel mapping shows up in ELRS like Crossfire and Tracer where you can assign a channel to the LQ etc...

I know all this is super easy in betaflight OSD and Kiss OSD. I really like using the solid regulators built into this system and the ease of camera and VTX wiring positioning. Currently on Tracer at the moment but have ELRS gear I'm looking to swap in.

Thanks for anyone's help in advance!

Linuxbarista, 2022-11-14:
Anybody?

slackista, 2023-03-15:
This is dead project apparently.

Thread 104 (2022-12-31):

OSD only shows with camera lens cap on

Bigjmf, 2022-12-31:
Hi Got everything wired and working OSD is working just fine when the camera lens cover is on as soon as I take it off the OSD disappears. Is there some setting that I am missing that I need to change?

Bigjmf, 2022-12-31:
I figured it never mind. just need to increase Camera Sync to 200. Working fine now

Closed 2022-12-31.

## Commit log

2018-07-13 Add Wolf PCB photo
2018-07-13 Add Wolf outline DXF
    [Wolf_Outline.dxf]
2018-07-13 Zip the DXF outline in an attempt to get Github Wiki to allow a proper download link
    [Wolf_Outline.dxf]
2018-07-15 Add Settings Panel Button image
